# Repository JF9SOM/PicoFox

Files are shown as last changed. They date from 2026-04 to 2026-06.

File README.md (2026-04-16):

# PicoFox – A Hackable 2m Fox Transmitter

**PicoFox** is an open source fox transmitter for the 2-meter amateur band, built around the
RP2040 microcontroller (the same chip used in the Raspberry Pi Pico). It’s designed to be simple,
functional, and easy to modify.

PicoFox works well as a standalone fox for portable or walking hunts, but it’s also a great platform
for experimentation. There's ample CPU, flash, and GPIO available if you want to add features like
sensors or interactivity. The transmitter can generate a frequency or phase modulated signal with up
to 2.5kHz (data) bandwidth.

## Key Features
- Transmits FM in the 144–148 MHz band (ITU Zone 1: 144–146 MHz).
- Configured by editing a text file — no software or terminal needed.
- Transmits any 5kHz 16-bit PCM WAV file.
- Automatic Morse code ID with configurable tone, speed, and spacing.
- RF output > 18dBm at full power. Down to ~ -20dBm with full attenuation.
- Charges over USB.
- Expansion header provides:
  - 12 GPIOs (including I2C, SPI, UART, ADC).
  - Regulated 3.3V and raw battery voltage.
  - Two additional SI5351 clock outputs

### Getting One

Fully assembled PicoFox units are available from [AI6YM.radio](https://ai6ym.radio/picofox). An
enclosure, battery, and antenna are included. I ship nearly anywhere in the world.

You can also build your own - both the hardware and software are open source for non-commercial use.
For commercial inquiries, contact [justin@ai6ym.radio](mailto:justin@ai6ym.radio).

## Configuration

To configure your PicoFox, connect it to any computer using a micro USB cable. It will appear as a
USB mass storage device (like a flash drive). Open `settings.txt` with a text editor and adjust the
configuration values as needed. Eject the drive, disconnect USB, and power cycle the PicoFox to
apply the new settings.

To reset to factory settings, delete `settings.txt`, eject the drive, disconnect USB, and power
cycle the PicoFox. A default settings file will be regenerated.

### Settings Overview

- `CALLSIGN`: Alphanumeric callsign (max 12 characters).
- `ITU_ZONE`: ITU zone where the transmitter operates (`1`, `2`, or `3`).
- `FREQ_MHZ`: Transmit frequency in MHz.
- `ATTENUATION`: Attenuation level `0` - `127`, approximately 0.25dB steps.
- `DUTY_CYCLE`: Transmit duty cycle percentage (`0–100`).
- `MORSE_WPM`: Morse ID speed in words per minute.
- `MORSE_FARNSWORTH_WPM`: Slower Farnsworth spacing speed (ignored if lower than `MORSE_WPM`).
- `MORSE_TONE`: Morse tone frequency (100–2000 Hz).
- `MORSE_TONE_VOL`: Morse tone volume percentage (`1–100`).

**Note:** Invalid or missing values may disable the transmitter or revert to safe defaults.

## Using the Transmitter

After configuring settings as described above. The transmitter will turn on following the
provided settings the next time it is turned on.

The transmitter may be powered by an external USB power supply or the internal battery. The internal
battery charges over USB but no indication is available to show battery charging.

**Note: The power switch must be ON to charge the battery over USB. The transmitter will run on USB
power with the switch OFF but the battery will NOT be charged.**

A full battery will last about five hours at 100% duty cycle, 

## Replacing the Audio File

To change the audio transmission, replace the `audio.wav` file in the device’s flash storage. The
audio must be sampled at **5kHz**, **mono** (one channel), and encoded as **signed 16-bit PCM WAV**.

Using **Audacity** (free software available for all major OSs):

1. Set "Project Rate (Hz)" to `5000`.
2. Import, record, or generate your audio.
3. Mix down to a single mono track.
4. Export as WAV using **Signed 16-bit PCM** encoding.
5. Name the file `audio.wav` and copy it to the device.
6. Eject the drive and disconnect USB.
7. Power cycle the PicoFox.

**Notes:**

- Improper format may prevent audio transmission or cause noise to be transmitted instead.
- The audio is transmitted, followed by the morse ID, and then the transmitter turns off if
  `DUTY_CYCLE < 100`. In this way the length of the audio determines the transmit cycle time and the
  frequency of morse code ID transmissions. **YOU ARE RESPONSIBLE FOR COMPLYING WITH LOCAL LAWS FOR
  TRANSMITTING YOUR CALLSIGN!**
- To restore the default audio, delete `audio.wav`, eject the drive, disconnect USB, and power cycle
  the PicoFox.

## Design Brief

An SI5351 clock generator, locked to a TCXO, provides the RF signal. Modulation is applied in
software by the RP2040. To achieve smooth FM output, modulation is handled on core 1 with
I<sup>2</sup>C running at 1 MHz. Register writes are minimized and no other devices are on
I<sup>2</sup>C0.

Core 0 manages flash operations. Most extensions or new features should run on core 0.

**Note:** Mounting the device as a USB mass storage device will interrupt clean modulation as both
cores are blocked during flash operations.

The SPI flash device is split into program memory and a FAT16 filesystem. The filesystem contains
a text file for user-supplied settings, an audio file for transmission, a second audio file
containing the generated morse code ID, and a hash file used to detect changes to the settings file.
Unexpected files are automatically deleted and missing files are re-created from defaults in the
firmware binary.

The design intentionally includes large amounts of free CPU cycles, RAM, and flash so that cool
things can be built on the PicoFox.

## Development Guide

### Build Environment Setup

- Install Arduino IDE >= 2.3.
- Install libraries - Adafruit SPIFlash, Adafruit TinyUSB, Etherkit Si5351.
- Install board package from [my fork of Arduino-Pico](https://github.com/ai6ym/arduino-pico). This
  will be merged upstream eventually but for now you'll need the changes in my fork.
- In `Tools -> Board` select the `Raspberry Pi RP2040/RP2350 Boards -> AI6YM PicoFox`.
- Connect your PicoFox and select the appropriate TTY / COM port.

On Linux it may be necessary to add udev rules for this device. The relevant rules from my system
are below. I have no idea how this works on other operating systems. Mac is probably similar,
Windows should not be used for software developement of any kind (or really anything).

```
# Make an RP2040 in BOOTSEL mode writable by all users, so you can `picotool`
# without `sudo`. 
SUBSYSTEM=="usb", ATTRS{idVendor}=="2e8a", ATTRS{idProduct}=="0003", MODE="0666"

# Symlink an RP2040 running MicroPython from /dev/pico.
#
# Then you can `mpr connect $(realpath /dev/pico)`.
SUBSYSTEM=="tty", ATTRS{idVendor}=="2e8a", ATTRS{idProduct}=="0005", SYMLINK+="pico"

# Adafruit TinyUSB stack.
SUBSYSTEM=="tty", ATTRS{idVendor}=="239a", ATTRS{idProduct}=="cafe", MODE="0666"
SUBSYSTEM=="usb", ATTRS{idVendor}=="239a", ATTRS{idProduct}=="cafe", MODE="0666"
```

### Compilation Settings

- `Flash Size`: `16MB (Sketch: 1MB, FS: 15MB)`
- `CPU Speed`: `TBD`
- `USB Stack`: `Adafruit TinyUSB`

If needed for some reason you could change the partition layout to give more space for the sketch.
Doing so would destroy all data but the code automatically formats the partition and writes
defaults.

All other settings are fine at default values.

### Recovering a Board

In general the UF2 upload process will work fine. Click the upload button, after compilation the IDE
will push the board into UF2 update mode, write the new binary, and then reset the board to normal
operation.

If that doesn't work try the following:
- Reset the board and try again. Just tap the `RESET` button on the board to reset the RP2040.
- Force the device into `BOOTSEL` mode. Hold the `BOOTSEL` button, tap the `RESET` button, and then
  release the `BOOTSEL` button.
- Force the device into `BOOTSEL` mode **AND** change `Tools -> Upload Method` to `PicoTool`.
- When all else fails grab a PicoProbe (or a Pico / Pico2 flashed with the PicoProbe binary),
  connect that to the debug header of the PicoFox, and change `Tools -> Upload Method` to
  `Picoprobe`.
- If all of the above fails, well, he's dead Jim.

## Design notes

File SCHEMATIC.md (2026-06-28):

# 回路図 / Schematic Reference

テキストベースの回路図。ブレッドボード配線・実装の参考用。  
詳細なピン対応表は [`HARDWARE.md`](HARDWARE.md)、部品の入手先は [`BOM.md`](BOM.md) を参照。

---

## 1. システム全体ブロック図

```
                        ┌─────────────────────────────────────────────────────┐
                        │                  PicoFox 基板                        │
                        │                                                      │
   USB-C ───────────────┤ USBLC6  BQ21040 ←── USB 5V                          │
   (充電/MSC)           │  (ESD)  (充電IC)                                     │
                        │             │                                        │
   LiPo ────────────────┤        +BATT (3.7V)                                  │
   3.7V                 │             │                                        │
                        │         AO3401A ─── SW (電源スイッチ)                │
                        │         AO3407A                                      │
                        │             │                                        │
                        │        ME6217C33 ──→ +3V3 (内部, 最大500mA)          │
                        │                                                      │
                        │   ┌──────────────────┐                               │
                        │   │     RP2040        │                               │
                        │   │  W25Q128 (Flash)  │                               │
                        │   │  ABM8-272 (12MHz) │                               │
                        │   └────────┬──────────┘                               │
                        │            │ 拡張ヘッダ J1                            │
                        └────────────┼────────────────────────────────────────┘
                                     │
              ┌──────────────────────┼──────────────────────┐
              │                      │                      │
    ┌─────────▼──────────┐  ┌────────▼───────┐   ┌─────────▼──────┐
    │     DRA818V        │  │ 144MHz BPF     │   │  スタートボックス│
    │  (134〜174MHz FM)  │  │ (HobbyPCB /    │   │  (SYNC回路)    │
    │  内蔵PA ≈1W        │  │  LC自作)       │   └────────────────┘
    │  UART制御          │  └────────┬───────┘
    └─────────┬──────────┘           │
              │ RF Out               │ RF
              └──────────────────────┘
                                     │
                              ┌──────▼──────┐
                              │  SMAコネクタ │
                              │  50Ω アンテナ│
                              └─────────────┘
```

---

## 2. RP2040 ↔ DRA818V 接続図

```
   RP2040 (PicoFox 拡張ヘッダ J1)          DRA818V
   ┌──────────────────────────┐            ┌───────────────────────────┐
   │                          │            │                           │
   │  GPIO 8  (UART1 TX) ─────┼────────────┼──→ RXD   (コマンド受信)  │
   │                          │            │                           │
   │  GPIO 9  (UART1 RX) ←───┼────────────┼─── TXD   (応答送信)      │
   │                          │            │                           │
   │  GPIO10  (PTT)      ─────┼────────────┼──→ PTT   LOW=TX, HIGH=RX │
   │                          │            │                           │
   │  GPIO11  (PDN)      ─────┼────────────┼──→ PDN   HIGH=ON, LOW=PD │
   │                          │            │                           │
   │  GPIO12  (SQ_IN)    ←───┼────────────┼─── SQ    スケルチ出力     │
   │                     (未使用)          │         (Fox送信機では不使用)│
   │                          │            │                           │
   │  GPIO15  (PWM Audio)─────┼──[LPF]─────┼──→ MIC   音声入力        │
   │                          │            │                           │
   │  +3V3 ──────────────[外部3.3V/1A]─────┼──→ VCC   3.3V / 最大700mA│
   │                          │            │                           │
   │  GND  ──────────────────┼────────────┼─── GND                   │
   │                          │            │                           │
   │  GPIO13  (SYNC)     ←───┼─────────── ┼─ (スタートボックスへ)      │
   └──────────────────────────┘            └───────────────────────────┘

信号レベルはすべて 3.3V CMOS。レベル変換不要。
全信号線の長さは 10cm 以内を推奨。
```

---

## 3. PWM音声出力 LPF 回路図

RP2040のGPIO15から出力される10bit PWM（約122kHz）をアナログ音声に変換し、DRA818VのMICピンへ供給する。

```
                    R1            DRA818V
  GPIO15 ──────────[1kΩ]──────┬──→ MIC pin
  (PWM ~122kHz,               │
   10bit, 3.3Vp-p)          [C1]
                             [33nF]
                               │
                              GND (DRA818V GND と同一点)

  周波数特性:
  ────────────────────────────────────────────────
   周波数      ゲイン    用途
  ────────────────────────────────────────────────
   1 kHz       0 dB     モールストーン（通過）
   4.8 kHz    -3 dB     カットオフ周波数 fc
   10 kHz    -13 dB     減衰（PWM成分を抑制）
   122 kHz   -48 dB     PWMキャリア（十分減衰）
  ────────────────────────────────────────────────

  fc = 1 / (2π × 1kΩ × 33nF) ≈ 4.8 kHz

  代替値: R=1kΩ, C=47nF → fc ≈ 3.4 kHz（偏移を絞りたい場合）

  注意: C1 は DRA818V MICピンのすぐ近く（1cm以内）に配置すること。
```

---

## 4. SYNC・スタートボックス回路図

### 4-a. フォックス側 SYNC 入力回路（1台分）

```
  3.5mm ステレオジャック
  ┌─────────────┐
  │ Tip ────────┼──[R: 100Ω]───── GPIO13 (SYNC_PIN)
  │             │                    │
  │             │               [内部プルアップ 50kΩ]
  │             │                    │
  │ Ring ───────┼──────────────── +3V3
  │             │
  │ Sleeve ─────┼──────────────── GND
  └─────────────┘

  平常時: GPIO13 = HIGH（内部プルアップ）
  同期時: スタートボックスがTipをGNDに落とす → GPIO13 = LOW → エポックリセット
```

### 4-b. スタートボックス回路

```
                         3.5mm ジャック OUT
                         ┌─────────────┐
  +3V3 ──[10kΩ]──┬───── │ Tip         ├── ケーブルへ
                 │       │             │
                [SW1] ── │             │
  (タクトスイッチ)│       │ Ring ───────┼── GND
                GND      │ Sleeve ─────┼── GND
                         └─────────────┘

  SW1 OFF (平常): Tip = HIGH（プルアップ）
  SW1 ON  (押下): Tip = GND  → 全Foxの GPIO13 が LOW → 同期

  注: フォックス側の内部プルアップ（50kΩ）が5台並列になるため
      合成抵抗 ≈ 10kΩ。スタートボックスの外部プルアップは省略可。
```

### 4-c. 5台同時接続図（デイジーチェーン）

```
  スタートボックス
  ┌─────────────────┐
  │                 │
  │  SW1 ─── GND   │
  │   │             │
  │  [100Ω]        │
  │   │             │
  │  Tip────────────┼─── ケーブル1 ──┬── Fox1: Tip→[100Ω]→GPIO13
  │  Ring───── GND ─┼─── ケーブル1 ──┘   Fox1: Ring→GND
  │                 │
  └────────┬────────┘
           │ OUT ジャック
           │
           ├── ケーブル2 ──┬── Fox2: Tip→[100Ω]→GPIO13
           │              └── Fox2: Ring→GND
           │
           ├── ケーブル3 ──┬── Fox3: Tip→[100Ω]→GPIO13
           │              └── Fox3: Ring→GND
           │
           ├── ケーブル4 ──┬── Fox4: Tip→[100Ω]→GPIO13
           │              └── Fox4: Ring→GND
           │
           └── ケーブル5 ──┬── Fox5: Tip→[100Ω]→GPIO13
                          └── Fox5: Ring→GND

  TipラインはスタートボックスとFox5本が並列接続。
  SW1 を押すと全 Fox の GPIO13 が同時に LOW になる。
```

---

## 5. 電源回路図

```
  USB-C コネクタ
       │
  USBLC6-2SC6 (ESD保護)
       │
   VBUS (+5V) ──────────────────────────── RP2040 (USB電源時)
       │
  BQ21040DBVR (LiPoチャージャ)
       │ 充電電流
       ▼
  LiPo 3.7V ◄──── JST PH コネクタ ◄──── LiPo バッテリー (2000〜3000mAh)
       │
  AO3407A / AO3401A (電源スイッチ MOSFET)
       │
   SW (スライドスイッチ)
       │
  +BATT (3.7〜4.2V) ─────────────────────────────────────────────┐
       │                                                          │
  ME6217C33M5G (3.3V LDO, 最大500mA)                             │
       │                                                          │
   +3V3_INT ──→ RP2040, Si5351, W25Q128, USBLC6                  │
   (内部 3.3V)   各種プルアップ、ロジック回路                     │
                                                                  │
                                                         ┌────────▼────────┐
                                                         │  外部 3.3V 電源  │
                                                         │  (1A以上、別途)  │
                                                         │ ※DRA818V専用    │
                                                         └────────┬────────┘
                                                                  │
                                                            +3V3_DRA (3.3V / 1A)
                                                                  │
                                                             DRA818V VCC
                                                         (送信時 最大 700mA)

  デカップリング:
    +3V3_INT  各ICのVCC直近に 100nF + 1uF を配置
    +3V3_DRA  DRA818V VCCに 100uF(電解) + 100nF(セラミック) を並列配置
    +BATT     バッテリ端子近傍に 100uF を配置

  グランド接続:
    RP2040 GND ─┐
    DRA818V GND─┼── 1点でのみ接続（グランドループを防ぐ）
    BPF GND  ───┘
```

---

## 6. RF信号経路・アンテナ接続

```
  DRA818V
  ┌─────────────────────────┐
  │                         │
  │  内蔵 VCO + PLL          │
  │  134〜174 MHz            │
  │  内蔵 PA (≈1W / 30dBm)  │
  │                         │
  │  ANT ───────────────────┼── SMAケーブル (10cm, 50Ω) ──→ BPF IN
  │                         │
  └─────────────────────────┘

  144MHz BPF (HobbyPCB または LC自作)
  ┌──────────────────────────────┐
  │                              │
  IN ──┤ 通過帯域: 144〜146MHz    ├── OUT
  │    │ 挿入損失: ≈ 1〜2dB      │
  │    │ スプリアス抑制: > 40dBc  │
  │                              │
  └──────────────────────────────┘
       │
       └── SMAケーブル (10cm, 50Ω) ──→ SMAコネクタ (エッジマウント)
                                                │
                                          1/4λ アンテナ
                                          145MHz: 51.5cm
                                          (またはホイップ、Jポール等)

  インピーダンス: 全経路 50Ω
  BPFとSMAコネクタ間の配線は 5cm 以内を推奨。
  同軸ケーブルのシールドはグランドプレーンに確実に接続すること。

  アンテナ長の目安 (145.660 MHz):
  ────────────────────────────────
  1/4λ      = 300,000 / 145.660 / 4 ≈ 51.5 cm
  1/2λ DP   = 各エレメント ≈ 51.5 cm × 2
  5/8λ GP   ≈ 64.4 cm (利得 +3dBi)
  ────────────────────────────────
```

---

## 7. 完成系の信号フロー（まとめ）

```
  [LiPo] → [電源SW] → [LDO 3.3V] → [RP2040]
                                        │
                    ┌───────────────────┤
                    │                   │
              [UART 9600bps]      [PWM GPIO15]
                    │                   │
                    ▼                 [LPF]
              [DRA818V]                 │
              周波数設定 ←──────────── MIC
              PTT制御   ←── GPIO10
              PDN制御   ←── GPIO11
                    │
                   RF出力 (145.660 MHz, ≈1W)
                    │
                [144MHz BPF]
                    │
               [SMAコネクタ]
                    │
                [アンテナ]
                    ↑
              電波輻射 145.660/145.780 MHz FM

  [SYNC入力 GPIO13] ←── [スタートボックス SW1] ←── 運営者
       │
  エポックリセット → 60秒サイクル再開始 → 全Fox同期
```

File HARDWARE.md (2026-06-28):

# ハードウェア接続図 / Hardware Connection Guide

DRA818V換装構成の配線リファレンス。  
**注意**: DRA818V統合はStep 4以降の作業。現行ファームウェアはSi5351構成で動作する。

---

## 1. RP2040 ↔ DRA818V ピン接続表

| RP2040 GPIO | 信号名 | DRA818V ピン | 説明 |
|:---:|---|:---:|---|
| GPIO 8 | UART TX | RXD | コマンド送信（9600bps） |
| GPIO 9 | UART RX | TXD | 応答受信 |
| GPIO 10 | PTT | PTT | LOW=送信, HIGH=受信 |
| GPIO 11 | PDN | PDN | HIGH=通常動作, LOW=パワーダウン |
| GPIO 12 | SQ_IN | SQ | スケルチ出力（fox送信機では未使用） |
| GPIO 15 | PWM Audio | MIC | 音声入力（LPF経由）|
| 3V3 | VCC | VCC | 3.3V電源 |
| GND | GND | GND | グランド |

### 電源について

DRA818Vは3.3Vで動作するが**送信時に最大700mA**を消費する。  
PicoFox内蔵のME6217C33M5G LDO（最大500mA）では不足するため、**外部3.3V電源または5V→3.3V降圧モジュール（1A以上）**を別途用意すること。

---

## 2. RP2040 ↔ Si5351 ピン接続表（現行PicoFox基板）

| RP2040 GPIO | 信号名 | Si5351 ピン | 説明 |
|:---:|---|:---:|---|
| GPIO 0 | I2C0 SDA | SDA | I2Cデータ（1MHz） |
| GPIO 1 | I2C0 SCL | SCL | I2Cクロック（1MHz） |
| GPIO 2 | AMP_EN | — | アンプ制御（LOW=有効） |
| GPIO 4 | ATTN_LE | — | BVA1761アッテネータLatch Enable（r3のみ） |
| 3V3 | VCC | VDD | 3.3V電源 |
| GND | GND | GND | グランド |

Si5351のCLK0出力がRFアンプ（H5VU06B）に接続される。  
CLK1・CLK2は拡張ヘッダ経由で利用可能（将来の3.5MHz対応に使用予定）。

---

## 3. PWM LPF 回路定数

DRA818V MICピンへの音声入力用ローパスフィルタ。

```
GPIO 15 (PWM) ──[R1: 1kΩ]──┬── DRA818V MIC
                            │
                          [C1: 33nF]
                            │
                           GND
```

| 定数 | 値 | 計算根拠 |
|---|-----|---|
| R1 | 1 kΩ | インピーダンス整合 |
| C1 | 33 nF | fc = 1/(2π×1kΩ×33nF) ≈ **4.8 kHz** |
| PWM周波数 | 約122 kHz | 125MHz ÷ 1024 (10bit) |
| 通過帯域 | 〜4.8 kHz | 5kHzサンプルレート音声を通過 |

**代替値（よりシャープなカットオフ）**: R=1kΩ, C=47nF → fc ≈ 3.4 kHz  
DRA818Vの最大周波数偏移はデフォルト設定で±5kHz（25kHz帯域幅）または±2.5kHz（12.5kHz帯域幅）。

---

## 4. BVA1761 アッテネータ（r3基板のみ）

PicoFox r3にはSi5351出力後段にBVA1761デジタルアッテネータが搭載されている。

| RP2040 GPIO | 信号 | 説明 |
|:---:|---|---|
| GPIO 0 | DATA（SDA兼用） | シリアルデータ（LSBファースト） |
| GPIO 1 | CLK（SCL兼用） | シリアルクロック |
| GPIO 4 | LE | ラッチイネーブル（パルスで設定確定） |

Si5351初期化前にビットバング方式で設定する（ファームウェア実装済み）。  
DRA818V換装後はこのアッテネータは使用しない（DRA818V側でRFレベルを制御）。

---

## 5. ブレッドボード配線の注意事項

### RF系
- SMAコネクタからBPF、BPFからDRA818Vアンテナピンまでの配線は**できるだけ短く**（5cm以内）
- RFラインはグランドプレーンに近接させてインピーダンス50Ωを維持
- DRA818VのRFピンは直接触らない（静電気に弱い）

### 電源系
- DRA818V電源ラインには**100μF電解コンデンサ + 100nFセラミックコンデンサ**を並列に配置
- PTT切り替え時の電源ノイズが RP2040 にカップリングしないよう電源を分離する
- RP2040とDRA818Vのグランドは**1点でのみ接続**（グランドループを防ぐ）

### UART
- GPIO 8/9はPicoFox拡張ヘッダ（J1）経由で引き出す
- DRA818V TXD/RXDは3.3Vロジックなのでレベル変換不要

### PWM Audio
- LPFのC1（33nF）はDRA818V MICピンのすぐ近くに配置
- LPFのグランドはDRA818V GNDに直結（RP2040 GNDと同一点でのみ接続）

---

## 6. SYNC配線（スタートボックス接続）

### SYNC_PINのピン番号

| RP2040 GPIO | 信号 | 方向 | 説明 |
|:---:|---|:----:|---|
| GPIO 13 | SYNC | 入力 | アクティブLOWパルスで60秒サイクルをリセット。内部プルアップ有効。 |

### 同期ケーブル配線図

スタートボックスから各フォックスに3.5mmステレオケーブルを数珠繋ぎにする。

```
スタートボックス
┌────────────────────────────┐
│  [SW1]                     │
│   ├── 100Ω ── SYNC(Tip)   ●── 3.5mm ジャック OUT
│  GND ────────── GND(Ring) ●
└────────────────────────────┘
         │
         ├── ケーブル → Fox 1 (GPIO 13 / GND)
         ├── ケーブル → Fox 2 (GPIO 13 / GND)
         ├── ケーブル → Fox 3 (GPIO 13 / GND)
         ├── ケーブル → Fox 4 (GPIO 13 / GND)
         └── ケーブル → Fox 5 (GPIO 13 / GND)
```

各フォックス側のジャック配線:

```
3.5mm ステレオジャック（各Fox搭載）
  Tip   ── 100Ω ── GPIO 13 (SYNC_PIN, INPUT_PULLUP)
  Ring  ──────────── GND
  Sleeve ─────────── GND（シールド）
```

**直列100Ω抵抗**はESD保護と静電気対策。省略可能だが推奨。

### スタートボックス回路

```
      VCC (3.3V または 5V)
         │
        [10kΩ] ← プルアップ（フォックス側の内部プルアップで代替可）
         │
SYNC ───┤├── SW1 (タクトスイッチ) ── GND
         │
        [100Ω] ── 3.5mm Tip（OUT）
         │
       3.5mm Ring/Sleeve ── GND
```

**操作手順**:
1. 全フォックスをSYNCケーブルで接続し電源を投入
2. スタートボックスのSW1を押す（SYNC線がLOWになり全フォックスのエポックがリセット）
3. SW1を離す（全フォックスが同時に60秒サイクルを再開始）

**注意**:
- SYNCケーブルはイベント開始直前に接続し、完了後は外す（誤同期防止）
- ケーブルの接触不良でSYNCが入らない場合、各局は電源投入時刻を基準に動作する

---

## 7. 接続確認チェックリスト（組み立て後）

- [ ] DRA818V VCC = 3.3V（テスター確認）
- [ ] DRA818V PDN = HIGH（テスター確認）
- [ ] Serial1でAT+DMOCONNECTに"+DMOCONNECT:0"が返る
- [ ] PTT LOWでRP2040の電源電圧が3.1V以上を維持（電流確認）
- [ ] RTL-SDRで145.660 MHzにキャリアが見える
- [ ] モールスIDが受信できる

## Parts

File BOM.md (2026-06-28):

# 部品表 (BOM) / Bill of Materials

日本ARDF競技向けPicoFox（DRA818V構成）の統合部品表。  
**前提**: RF送信モジュールはDRA818Vを使用する。Si5351A関連部品はオリジナルPicoFox基板に搭載済みのため、新規調達は不要（注記参照）。

価格は2024年時点の参考値。為替・在庫状況により変動する。  
数量は特記のない限り **フォックス1台分**。

---

## 1. メインコントローラ

| 部品名 | 型番 | 数量 | 用途 | 入手先 | 参考価格（円） |
|---|---|:----:|---|---|:---:|
| MCU | RP2040 | 1 | メインマイコン（QFN-56） | Mouser Japan / DigiKey Japan | 150 |
| SPI Flash | W25Q128JVS | 1 | 16MB ファームウェア・ファイルシステム | DigiKey Japan / AliExpress | 120 |
| クリスタル | ABM8-272 12MHz | 1 | RP2040 USB PLL用 | DigiKey Japan | 200 |

**小計: 約470円**

---

## 2. RF送信モジュール

| 部品名 | 型番 | 数量 | 用途 | 入手先 | 参考価格（円） |
|---|---|:----:|---|---|:---:|
| VHF FM送受信モジュール | **DRA818V** | 1 | 134〜174MHz FM変調、内蔵PA（出力約1W） | AliExpress / eBay | 700〜1,200 |
| SMAケーブル | SMA-SMA 10cm | 1 | DRA818V〜BPF間RF接続 | 秋月電子 / AliExpress | 200〜400 |
| ピンヘッダ | 2.54mm オス 1×6 | 1 | 拡張ヘッダ経由DRA818V接続用 | 秋月電子 | 50 |

> **オリジナル構成（DRA818V使用時は不要）**: Si5351A-B-GT、TCXO（TG2016SMN 25MHz）、BVA1761デジタルアッテネータ、RF MMIC（H5VU06B）はオリジナルPicoFox基板に搭載済み。DRA818V換装後はこれらを使用しない。

**小計: 約950〜1,650円**

---

## 3. フィルタ

| 部品名 | 型番・仕様 | 数量 | 用途 | 入手先 | 参考価格（円） |
|---|---|:----:|---|---|:---:|
| 144MHz BPF | HobbyPCB 144MHz BPF | 1 | スプリアス抑制用バンドパスフィルタ | hobbypcb.com（海外通販） | 1,500〜2,000 |
| 144MHz BPF（代替） | 自作 LC回路（コイル+コンデンサ） | 1 | 上記が入手困難な場合の代替 | 秋月電子 | 200〜500 |
| PWM LPF | R=1kΩ + C=33nF | 1組 | PWM音声→DRA818V MICピン平滑化 | 秋月電子 | 50 |

> BPFはHobbyPCBまたは自作のいずれか1つを選択。両方は不要。

**小計: 約250〜2,050円**（BPF選択による）

---

## 4. 電源

| 部品名 | 型番 | 数量 | 用途 | 入手先 | 参考価格（円） |
|---|---|:----:|---|---|:---:|
| LiPoチャージャ | BQ21040DBVR | 1 | USB-Cでのバッテリー充電 | DigiKey Japan / Mouser Japan | 200 |
| LDOレギュレータ | ME6217C33M5G | 1 | 3.3V生成（SOT-23-5） | AliExpress / DigiKey Japan | 80 |
| USB ESD保護 | USBLC6-2SC6 | 1 | USB端子のESD保護 | Mouser Japan / DigiKey Japan | 100 |
| MOSFETスイッチ | AO3401A | 1 | 電源スイッチング（P-ch SOT-23） | 秋月電子 / AliExpress | 30 |
| MOSFETスイッチ | AO3407A | 1 | 電源スイッチング（P-ch SOT-23） | 秋月電子 / AliExpress | 30 |
| LiPoバッテリー | 3.7V 2000〜3000mAh JST PH | 1 | 主電源（約5時間@フル送信） | 秋月電子 / AliExpress | 800〜1,500 |
| USB-Cレセプタクル | HC-TYPE-C-16P-01A | 1 | 充電・USB MSC接続 | AliExpress / 千石電商 | 80 |
| スライドスイッチ | SK12D07VG5 | 1 | 電源ON/OFF | 秋月電子 / 千石電商 | 30 |
| バッテリコネクタ | JST PH 2pin水平 | 1 | LiPoバッテリー接続 | 秋月電子 / 千石電商 | 50 |

> **DRA818V送信時の電流**: 最大700mA。内蔵LDOだけでは不足するため、**外部3.3V/1A以上の電源ラインをDRA818Vに直結**すること（[`HARDWARE.md`](HARDWARE.md) §1参照）。

**小計: 約1,400〜2,100円**

---

## 5. 同期・スタートボックス

フォックス全台の60秒サイクルを同時起動するためのSYNCシステム。  
スタートボックス部品（ケース等）は**5台分で1セット**。

### フォックス搭載部品（1台ごと）

| 部品名 | 型番・仕様 | 数量 | 用途 | 入手先 | 参考価格（円） |
|---|---|:----:|---|---|:---:|
| 3.5mmステレオジャック | MJ-354W / SJ-3523-SMT 等 | 1 | SYNCケーブル受け口（Tip=SYNC, Ring=GND） | 秋月電子 / 千石電商 | 60〜100 |
| 抵抗 | 100Ω 1/4W | 1 | SYNC線ESD保護 | 秋月電子 | 5 |

**フォックス搭載小計: 約65〜105円/台**

### スタートボックス（5台共用・1セット）

| 部品名 | 型番・仕様 | 数量 | 用途 | 入手先 | 参考価格（円） |
|---|---|:----:|---|---|:---:|
| 3.5mmステレオジャック（パネル用） | MJ-073N 等 | 2 | IN/OUTデイジーチェーン用 | 秋月電子 / 千石電商 | 80〜150 |
| 3.5mmステレオケーブル | 1〜2m オス-オス | 5本 | スタートボックス〜各フォックス間 | 100円ショップ / AliExpress | 500〜1,500 |
| タクトスイッチ | 6mm角、高さ5mm以上 | 1 | スタートボタン | 秋月電子 | 20 |
| 抵抗 | 100Ω 1/4W | 1 | SYNC線ESD保護 | 秋月電子 | 5 |
| プラスチックケース | タカチ SW-65B 等（65×50×20mm） | 1 | スタートボックス筐体 | 秋月電子 / 千石電商 | 300〜600 |

**スタートボックス小計: 約905〜2,275円（5台分）**

---

## 6. パッシブ部品・その他

| 部品名 | 仕様 | 数量 | 用途 | 入手先 | 参考価格（円） |
|---|---|:----:|---|---|:---:|
| コンデンサ | 100nF 0402 | 多数 | デカップリング | 秋月電子 / AliExpress | 200（アソート） |
| コンデンサ | 1uF / 10uF 0402 | 数個 | バイパス・電源平滑 | 秋月電子 | 150 |
| インダクタ | 68nH / 270nH 0402 | 各数個 | RF整合回路（Si5351構成用） | Mouser Japan / AliExpress | 300 |
| フェライトビーズ | 0402 | 数個 | 電源ノイズ除去 | 秋月電子 / AliExpress | 100 |
| 抵抗 | 各種 0402 | 多数 | プルアップ・分圧等 | 秋月電子 | 200（アソート） |
| ダイオード | 1N4148WS SOD-323 | 数個 | 逆流防止等 | 秋月電子 / 千石電商 | 50 |
| LED | 側面発光 1206 | 1 | ステータス表示 | 秋月電子 | 30 |
| SMAコネクタ | SMA エッジマウント | 1 | アンテナ接続 | 秋月電子 / Mouser Japan | 150 |
| タクトスイッチ | 6mm角 SMD | 1 | RESETボタン | 秋月電子 / 千石電商 | 20 |
| 拡張ヘッダ | 2×10 2.54mmピッチ | 1 | GPIO拡張 | 秋月電子 | 80 |

**小計: 約1,280円**

---

## 合計概算

### フォックス1台あたり

| カテゴリ | 下限（円） | 上限（円） |
|---|---:|---:|
| 1. メインコントローラ | 470 | 470 |
| 2. RF送信モジュール | 950 | 1,650 |
| 3. フィルタ（BPF含む） | 250 | 2,050 |
| 4. 電源（LiPo含む） | 1,400 | 2,100 |
| 5. 同期（フォックス分のみ） | 65 | 105 |
| 6. パッシブ部品・その他 | 1,280 | 1,280 |
| **合計（1台）** | **4,415** | **7,655** |

### スタートボックス（5台共用）

| | 下限（円） | 上限（円） |
|-|---:|---:|
| スタートボックス一式 | 905 | 2,275 |
| **1台あたり按分** | **181** | **455** |

### 5台フルセット合計目安

| | 下限（円） | 上限（円） |
|-|---:|---:|
| フォックス × 5台 | 22,075 | 38,275 |
| スタートボックス × 1セット | 905 | 2,275 |
| **総合計** | **約23,000** | **約40,500** |

> HobbyPCB BPFを使用した場合は上限寄り、LC自作BPFの場合は下限寄りになる。  
> オリジナルPicoFox基板（Si5351構成）を流用する場合、カテゴリ1・6の部品は調達不要のため1台あたり約1,750〜3,800円の削減になる。

---

## 入手先リンク（参考）

| ショップ | URL | 特徴 |
|---|-----|---|
| 秋月電子通商 | akizukidenshi.com | 国内最大手、即日発送 |
| 千石電商 | sengoku.co.jp | 秋葉原実店舗あり |
| Mouser Japan | mouser.jp | 正規代理店、幅広い品揃え |
| DigiKey Japan | digikey.jp | 正規代理店、在庫豊富 |
| AliExpress | aliexpress.com | 安価だが納期2〜4週間 |
| eBay | ebay.com | DRA818V等のモジュール類 |
| HobbyPCB | hobbypcb.com | ARDF・アマチュア無線向けBPF専門 |

---

## 注意事項

- 本機は自作のアマチュア無線機器です。日本国内で送信するには、アマチュア局免許状が必要ですが、自作機器の場合、JARDの保証認定を受けることでアマチュア局の開設または変更申請が可能です。
- HobbyPCB BPFはUSAからの取り寄せ。代替としてMini-Circuits等のSAWフィルタも検討可能。
- SMDパッシブ部品は秋月電子の「抵抗・コンデンサアソートセット」が割安。
- LiPoバッテリーは航空便不可のため、AliExpressからの発送に注意。

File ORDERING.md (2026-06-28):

# 発注ガイド / Ordering Guide

5台フルセット（フォックス5台＋スタートボックス1式）を前提とした発注手順。  
価格・在庫は変動するため、発注前に各ショップで最新情報を確認すること。

---

## 1. 発注先一覧

| ルート | ショップ | リードタイム | 特徴 |
|---|---|:---:|---|
| 🇺🇸 米国 | rfpowertools.com | 2〜3週間 | 144MHz BPF専門。品質安定、まとめ買い推奨 |
| 🇨🇳 中国 | AliExpress | 2〜4週間 | DRA818V・測定器。偽物に注意 |
| 🇯🇵 国内 | 秋月電子通商 | 翌日〜3日 | パッシブ部品・Pico・スイッチ類 |
| 🇯🇵 国内 | Amazon.co.jp | 翌日〜2日 | 急ぎの代替。割高な場合が多い |

---

## 2. 部品別発注先

### 🇺🇸 rfpowertools.com（米国）

**発注品目: 144MHz BPF × 5**

| 品目 | 数量 | 単価目安 | 合計目安 |
|---|:----:|---:|---:|
| 144MHz Band Pass Filter | 5 | $12〜$18 | $60〜$90 |
| 国際送料（USPS First Class / Priority） | — | $15〜$25 | — |
| **合計（5台分・送料込み）** | | | **$75〜$115（約11,000〜17,000円）** |

**まとめ買い推奨の理由**:
- 国際送料はほぼ固定のため、1個ずつ発注すると1個あたりの送料負担が大きい
- 5個発注で送料を5台に分散でき、1台あたりの追加コストを最小化できる
- BPFの予備（故障・紛失対策）として1〜2個多めに発注しておくと安心

**発注手順**:
1. rfpowertools.com にアクセスし "144MHz" または "2 meter BPF" で検索
2. 5個カートに追加
3. チェックアウト時に配送先を日本に設定、送料を確認
4. 支払いはクレジットカード（Visa/Mastercard）またはPayPal

> **備考**: BOM.mdでは hobbypcb.com も選択肢として記載している。rfpowertools.com で見つからない場合は hobbypcb.com の "144MHz BPF" も確認すること。

---

### 🇨🇳 AliExpress（中国直送）

#### DRA818V × 5

| 品目 | 数量 | 単価目安 | 合計目安 |
|---|:----:|---:|---:|
| DRA818V VHF Transceiver Module | 5 | ¥700〜¥1,200 | ¥3,500〜¥6,000 |
| 送料 | — | 無料〜¥300 | — |

**検索キーワード**: `DRA818V` / `DRA818 VHF module` / `SA818V`

**注意事項**:
- DRA818VはDRA818Uと**混同しやすい**。DRA818V = VHF（134〜174MHz）、DRA818U = UHF（400〜480MHz）。必ずVを確認すること
- SA818Vは後継・互換品として流通しているが、コマンド体系はほぼ同一
- 複数の出品者から1個ずつ試し買いして動作確認してから残数を発注するのが安全
- 評価件数1,000件以上・評価率95%以上のショップを選ぶ
- 到着後は即座にAT+DMOCONNECTで動作確認（[`TESTING.md §4`](TESTING.md) 参照）

#### tinySA Ultra × 1（スプリアス測定用）

| 品目 | 数量 | 単価目安 | 合計目安 |
|---|:----:|---:|---:|
| tinySA Ultra | 1 | ¥8,000〜¥12,000 | ¥8,000〜¥12,000 |
| 送料 | — | 無料〜¥500 | — |

**検索キーワード**: `tinySA Ultra` / `tiny SA ultra spectrum analyzer`

**⚠️ クローン品に注意**:
- tinySA Ultraには多数のクローン品・偽物が出回っている
- **公式販売店**: AliExpress内 "hugen79 official store" または "RF Technology store"
- 公式サイト: [tinySA.org](https://www.tinySA.org/) に正規販売店リストあり
- 価格が極端に安いもの（¥5,000以下）はクローン品の可能性が高い
- ファームウェアアップデートができないクローン品は測定精度が保証されない
- **購入前に tinySA.org の公式ショップリストで出品者を確認**すること

---

### 🇯🇵 秋月電子通商（国内）

**通販サイト**: akizukidenshi.com

#### Raspberry Pi Pico × 5（開発・テスト用）

> **注意**: PicoFox基板はRP2040チップを直接実装している。Picoモジュールは**PicoFox基板の代替にはならない**が、ファームウェア開発・動作確認・PicoProbeとしての利用に使える。

| 品目 | 数量 | 単価目安 | 合計目安 |
|---|:----:|---:|---:|
| Raspberry Pi Pico | 5 | ¥700〜¥800 | ¥3,500〜¥4,000 |

**活用方法**:
- ファームウェアの動作確認（RP2040互換）
- PicoProbeとしてPicoFox基板のデバッグに使用
- 1台をPicoProbeにするため2個あると便利

#### パッシブ部品・その他

| 品目 | 数量 | 単価目安 | 合計目安 |
|---|:----:|---:|---:|
| 抵抗アソートセット（1/4W） | 1 | ¥500〜¥800 | — |
| セラミックコンデンサアソート（0.1μF〜10μF） | 1 | ¥300〜¥500 | — |
| ジャンパワイヤセット | 1 | ¥300〜¥500 | — |
| SMAコネクタ（エッジマウント） | 5 | ¥150 | ¥750 |
| SMA-SMAケーブル 10cm | 5〜10 | ¥200〜¥400 | ¥1,000〜¥2,000 |
| 3.5mmステレオジャック（基板用） | 5 | ¥60〜¥100 | ¥300〜¥500 |
| 3.5mmステレオジャック（パネル用） | 2 | ¥80〜¥150 | ¥160〜¥300 |
| タクトスイッチ 6mm | 10 | ¥20 | ¥200 |
| スライドスイッチ | 5 | ¥30 | ¥150 |
| JST PHコネクタ 2pin | 5 | ¥50 | ¥250 |
| LiPoバッテリー 3.7V 2000mAh | 5 | ¥800〜¥1,200 | ¥4,000〜¥6,000 |
| タカチ SW-65B プラケース | 1 | ¥300〜¥600 | — |

**秋月電子での購入のコツ**:
- 通販注文は¥2,000以上で送料無料（2024年時点）
- 秋葉原実店舗では現物確認できる（日曜定休に注意）
- 部品の型番検索より「用途名」で検索した方が見つかりやすい場合あり

---

### 🇯🇵 Amazon.co.jp（予備・急ぎの場合）

以下は秋月電子に在庫がない場合や急ぎの場合の代替。基本的に秋月電子より割高。

| 品目 | 検索キーワード | 目安価格 |
|---|---|---:|
| Raspberry Pi Pico | "Raspberry Pi Pico SC0915" | ¥900〜¥1,200 |
| 3.5mmステレオケーブル 1m | "3.5mm ステレオ ミニプラグ" | ¥200〜¥500 |
| LiPoバッテリー | "リポバッテリー 3.7V 2000mAh JST PH" | ¥1,000〜¥2,000 |
| ブレッドボード | "ブレッドボード 400ポイント" | ¥300〜¥600 |

---

## 3. 発注の順序と優先度

リードタイムの長い海外便から先に発注する。

```
【第1週】海外発注（同時並行）
  ├─ rfpowertools.com: 144MHz BPF × 5（リードタイム 2〜3週間）
  └─ AliExpress:      DRA818V × 5    （リードタイム 2〜4週間）
                      tinySA Ultra × 1（リードタイム 2〜4週間）

【第1〜2週】国内発注（届き次第作業開始可能）
  └─ 秋月電子: Pico × 5、パッシブ部品、LiPo、ケーブル類
               → 翌日〜3日で到着

【第2週〜】到着次第作業開始
  ├─ 秋月電子部品到着 → ブレッドボードで配線確認・ファームウェア動作確認
  ├─ DRA818V到着     → TESTING.md §4 の初期確認手順を実施
  └─ BPF到着        → DRA818V + BPF でスプリアス測定（TESTING.md §3）

【第3〜4週】5局同時テスト
  └─ 全部品揃い次第 → TESTING.md §2 の5局同時起動テスト
```

**優先度まとめ**:

| 優先度 | 品目 | 理由 |
|:---:|---|---|
| ★★★ | DRA818V × 5 | 最重要部品、リードタイム長い |
| ★★★ | 144MHz BPF × 5 | 電波法上必須、リードタイム長い |
| ★★☆ | tinySA Ultra | スプリアス確認に必要 |
| ★★☆ | Pico × 5 | 開発・デバッグに即使える |
| ★☆☆ | パッシブ部品・ケーブル | 国内調達で即入手可能 |
| ★☆☆ | LiPoバッテリー | 国内調達、ただし航空便不可に注意 |

---

## 4. 注意事項

### LiPoバッテリーは航空便不可

- リチウムポリマーバッテリーは**国際航空便（SAL便含む）での輸送が禁止または制限**されている
- AliExpressで注文すると「船便のみ」となり**納期が6〜8週間**になる場合がある
- **国内（秋月電子・Amazonなど）での調達を強く推奨**

### tinySA Ultraのクローン品に注意

- AliExpressには公式品と外観が酷似したクローンが多数出回っている
- クローン品は測定精度・ファームウェアサポートが保証されない
- **必ず tinySA.org で公式販売店を確認してから発注する**
- 公式品には「tinySA.org」のロゴとシリアル番号が付属

### BPFは5台分まとめて発注

- rfpowertools.comへの国際送料は個数によらずほぼ固定
- 1台ずつ発注すると送料が5倍かかる
- 予備1〜2個を含め**6〜7個まとめて発注**するとコスト効率が良い

### 電波法：免許について

本機は自作のアマチュア無線機器です。日本国内で送信するには、アマチュア局免許状が必要ですが、自作機器の場合、JARDの保証認定を受けることでアマチュア局の開設または変更申請が可能です。

---

## 5. 発注チェックリスト

```
海外発注
[ ] rfpowertools.com: 144MHz BPF × 5（〜7）発注完了
[ ] AliExpress: DRA818V × 5 発注完了（公式ショップ確認済み）
[ ] AliExpress: tinySA Ultra × 1 発注完了（hugen79公式確認済み）

国内発注
[ ] 秋月電子: Raspberry Pi Pico × 5 発注完了
[ ] 秋月電子: LiPoバッテリー × 5 発注完了
[ ] 秋月電子: パッシブ部品・コネクタ・ケーブル類 発注完了
[ ] スタートボックス用ケース・スイッチ類 発注完了

到着確認
[ ] DRA818V AT+DMOCONNECT 動作確認（TESTING.md §4-Step1）
[ ] 144MHz BPF 通過損失確認（tinySA）
[ ] RTL-SDRでキャリア確認（免許取得後）
```

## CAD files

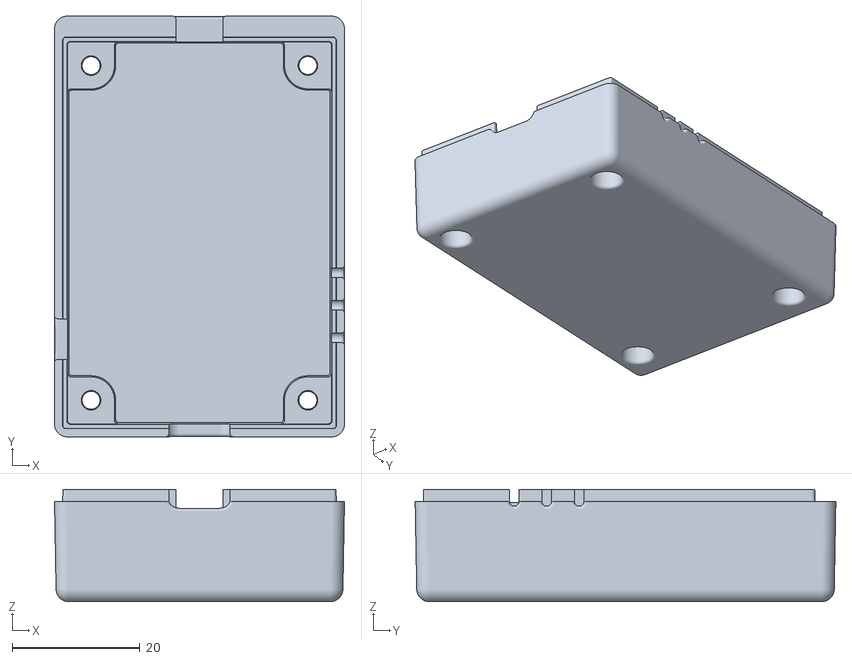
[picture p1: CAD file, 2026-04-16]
enclosure/Enclosure Bottom.stl
45.5 x 66.0 x 17.6

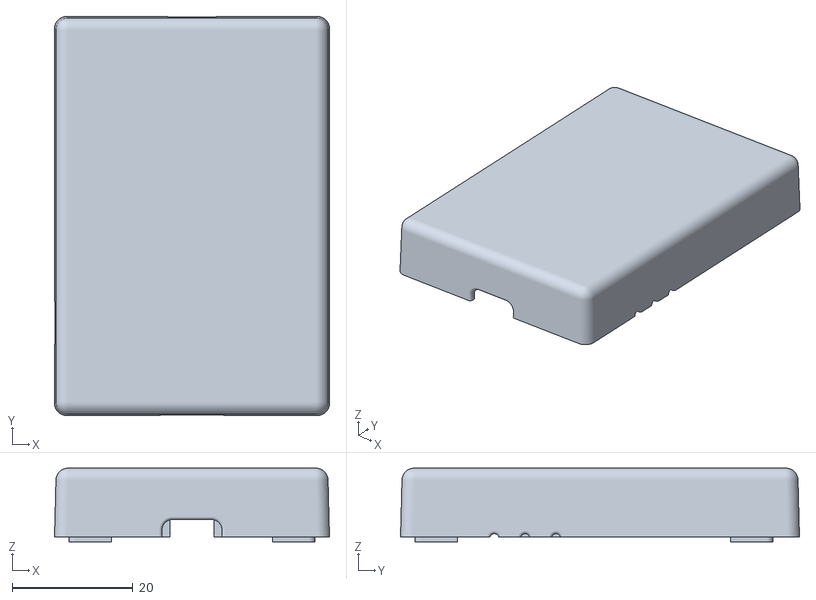
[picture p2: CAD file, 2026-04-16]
enclosure/Enclosure Top.stl
45.5 x 66.0 x 12.2

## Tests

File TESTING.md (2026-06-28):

# テスト手順書 / Testing Guide

---

## 1. RTL-SDRでの受信確認手順

### 必要機材
- RTL-SDR（RTL2832U系 USB SDRドングル）
- 145MHz帯対応アンテナ（1/4λ垂直 ≒ 51.5cm）
- PC: SDR# / GQRX / SDR++ いずれか

### 手順

**1-1. ソフトウェアセットアップ**
```
SDR# (Windows): sdrsharp.com からダウンロード
GQRX (Linux/Mac): sudo apt install gqrx-sdr
SDR++ (全OS): github.com/AlexandreRouma/SDRPlusPlus
```

**1-2. キャリア確認**
1. RTL-SDRを接続し、ソフトを起動
2. 周波数を `145.660 MHz` に設定
3. モード: `FM Narrow (NFM)`、帯域幅: `12.5 kHz`
4. PicoFoxに `CALLSIGN=JA1XXX`（任意）、`FOX_NUMBER=1` を設定して電源投入
5. 電源投入から **0秒以内** にキャリアが見えることを確認
6. 約10秒後にモールスID（MOE JA1XXX）が聞こえることを確認
7. 12秒でキャリアがOFFになることを確認

**1-3. スロットタイミング確認（単体）**
- SDR#のウォーターフォール表示で `FOX_NUMBER=1`〜`5` 各設定の送信開始時刻をストップウォッチで計測
- 期待値: Fox N の送信開始 = 電源投入から `(N-1) × 12秒`

---

## 2. 5局同時起動のスロット確認方法

### 事前準備
- PicoFox（またはシミュレーション用PC）を5台用意
- 各機に `FOX_NUMBER=1`〜`5` を設定（周波数はすべて同一: 145.660 MHz）

### シミュレーション方法（実機1台でテスト）
1台のPicoFoxで `FOX_NUMBER=1` から `5` に順次変更し、各スロット開始時刻を計測して確認する。

### 実機5台での確認手順

**2-1. 同時投入**
1. 5台を電源スイッチOFFの状態でUSB給電スタンバイ
2. 5台のスライドスイッチを**できるだけ同時**にON（±1秒以内が目標）
3. RTL-SDRのウォーターフォールを録画（OBS等）

**2-2. 確認ポイント**
```
秒数    期待動作
 0〜12  Fox1(MOE)のみ送信
12〜24  Fox2(MOI)のみ送信
24〜36  Fox3(MOS)のみ送信
36〜48  Fox4(MOH)のみ送信
48〜60  Fox5(MO5)のみ送信
60〜    Fox1(MOE)に戻る
```

**2-3. スロット重複の確認**
ウォーターフォール上で2局以上のキャリアが同時に見えた場合はスロット重複。  
原因: 電源投入タイミングのズレ（±1秒超）または `FOX_NUMBER` 設定ミス。

---

## 3. tinySAでのスプリアス測定手順

### 必要機材
- tinySA Ultra（推奨）またはtinySA Basic
- 50dBアッテネータ（直接接続時の保護用）
- SMA-SMAケーブル

### 手順

**3-1. 基本スプリアス測定**
1. PicoFoxのアンテナ端子に **50dBアッテネータ** を接続
2. アッテネータ出力をtinySAのIN端子に接続
3. tinySAの設定:
   - SPAN: `100 MHz〜500 MHz`（高調波確認）
   - RBW: `30 kHz`
4. PicoFoxを送信状態にして測定
5. 基本波（145.660 MHz）と第2高調波（291.32 MHz）、第3高調波（436.98 MHz）の電力差を確認

**3-2. 合否基準（電波法 第7条関係）**
- 基本波から **-60 dBc 以下**（スプリアス発射の強度の許容値）

**3-3. BPFありの比較測定**
HobbyPCB 144MHz BPFを挿入した状態で同様に測定し、スプリアス改善量を確認。

---

## 4. DRA818V到着後の初期確認手順

### Step 1: 単体動作確認（RP2040なし）

1. DRA818VのVCC=3.3V、GND接続
2. PDNをHIGHに固定
3. PCのUSB-シリアルアダプタ（3.3V）でRXD/TXDに接続
4. ターミナルソフト（Tera Term等）で `9600bps 8N1` に設定
5. 送信: `AT+DMOCONNECT\r\n`
6. 受信: `+DMOCONNECT:0` が返ればOK

**確認コマンド一覧**
```
AT+DMOCONNECT                          → ハンドシェイク確認
AT+DMOSETGROUP=1,145.6600,145.6600,0000,0,0000  → 145.660MHz / 12.5kHz設定
AT+DMOSETGROUP=0,145.6600,145.6600,0000,0,0000  → 145.660MHz / 25kHz設定
```

### Step 2: PTT動作確認

1. PTTピンをGNDに接続（LOW固定）
2. RTL-SDRで145.660 MHzにキャリアが見えるか確認
3. PTTをHIGHに戻してキャリアが消えるか確認

### Step 3: 音声変調確認

1. ファンクションジェネレータまたはスマートフォンの信号音（1kHzトーン）をMICピンに入力
2. PTT LOW（送信状態）
3. RTL-SDRのFMデモジュレータで1kHzトーンが聞こえるか確認
4. 音量を調整してFM偏移が ±2.5kHz（12.5kHz帯域幅モード）に収まるか確認

### Step 4: RP2040との統合確認

1. [`HARDWARE.md`](HARDWARE.md) の配線表に従って接続
2. `dra818_init()` を呼び出してシリアルモニタに初期化ログを確認
3. `dra818_set_group(145.660, DRA818_BW_12K5, 0)` を呼び出して周波数設定確認
4. `dra818_ptt_on()` でキャリア確認、`dra818_ptt_off()` でキャリア消滅確認
5. PWM音声出力からモールスIDが正常に変調されるか確認

---

## 5. 問題発生時のトラブルシューティング

| 症状 | 確認項目 |
|---|---|
| キャリアが出ない | isConfigured フラグ確認、CALLSIGN設定確認 |
| スロットがずれる | 全局同時投入できているか、millis()オーバーフロー確認 |
| DRA818Vが応答しない | UART TX/RXの逆接確認、PDN=HIGH確認、ボーレート確認 |
| モールスIDが聞こえない | callsign.wavが生成されているか、USBマウント中でないか |
| スプリアスが多い | BPFを挿入、Si5351駆動レベルを `SI5351_DRIVE_2MA` に維持 |
| 送信電力が低い | ATTENUATION=0 確認、DRA818V VCC電流確認（700mA必要） |

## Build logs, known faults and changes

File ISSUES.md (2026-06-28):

# 今後のタスク / Issue Tracker

GitHub Issuesの代替として、実装予定タスクをここで管理する。  
実際のIssueはリポジトリのIssuesタブへ移行予定。

---

## 進行中 / In Progress

なし

---

## 未着手 / Open

### Step 4: DRA818V UARTドライバ実装

**概要**: `dra818.h` / `dra818.cpp` のスタブを実機で検証し、`firmware.ino` に統合する。

**作業内容**:
- [ ] DRA818V実機でAT+DMOCONNECTの動作確認
- [ ] `dra818_init()` を `setup()` に組み込む
- [ ] `setSi5351Output()` の代替として `dra818_ptt_on/off()` を接続
- [ ] Si5351初期化ブロックをコンパイル時フラグ（`#ifdef USE_DRA818`）で分岐
- [ ] 設定変更時の再初期化対応（`FREQ_MHZ` 変更 → `dra818_set_group()` 再呼び出し）

**依存**: DRA818Vモジュール到着後に着手

---

### Step 5: PWM音声出力実装

**概要**: `pwm_audio.h` のスタブを実装し、`playAudio()` 内の `setFrequencyOffset()` を `pwm_audio_write()` に置き換える。

**作業内容**:
- [ ] `pwm_audio_init()` の実装（`pwm_gpio_to_slice_num` / `pwm_set_wrap` 設定）
- [ ] `pwm_audio_write(int16_t sample)` の実装
- [ ] `playAudio()` 内の `setFrequencyOffset(deviation)` を `pwm_audio_write(sample)` に置き換え
- [ ] LPF定数の実測（オシロスコープまたはSDRで波形確認）
- [ ] `AUDIO_PWM_SCALE` 定数の調整（FM偏移が ±2.5kHz に収まるよう調整）

**依存**: Step 4完了後、DRA818V実機でのテスト必要

---

### Step 6: 実機統合テスト

**概要**: Si5351構成とDRA818V構成を切り替えてARDF競技として動作することを確認する。

**作業内容**:
- [ ] 単体動作確認（Fox 1台、RTL-SDRで受信）
- [ ] 5台同時起動でスロット確認（[TESTING.md §2](TESTING.md) 参照）
- [ ] tinySAでスプリアス測定（[TESTING.md §3](TESTING.md) 参照）
- [ ] フィールドテスト（実際の競技コースで方向探知確認）
- [ ] バッテリー持続時間の実測

**依存**: Step 4・5完了後

---

## 将来の拡張 / Future

### 80m（3.5MHz）対応

**概要**: Si5351のCLK1出力を使って3.5MHz帯のARDFフォックスとして動作させる。

**検討事項**:
- Si5351 CLK1は拡張ヘッダ（J1）経由で利用可能
- 3.5MHz帯では出力レベルが低いため外部アンプが必要（例: IRF510を使ったAM/DSBアンプ）
- JARL ARDF規定では3.5MHz帯は80m部門として独立した競技
- 変調方式: AM（3.5MHz帯はAM変調が標準）← Si5351のPLL dithering方式では困難、DAC追加を検討

**参考**: Si5351 CLK1のピン番号 → 拡張ヘッダJ1のピン配置を確認すること

---

### GPS同期対応

**概要**: 1PPSシグナルを使ってすべてのフォックスを絶対時刻で同期する。現状は電源同時投入による相対同期。

**検討事項**:
- GPSモジュール（u-blox M8N等）を拡張ヘッダ経由で接続
- 1PPSパルスで `millis()` を補正 → 60秒サイクルの絶対アライメント
- 利点: 電源投入タイミングのズレを±1ms以内に補正可能
- 欠点: コスト増（GPSモジュール ≈ 1,500〜3,000円）・GPS取得まで送信遅延

---

### RTCによる自動電源制御

**概要**: 競技開始・終了時刻をあらかじめ設定し、RTC（DS3231等）で自動ON/OFFを制御する。

**検討事項**:
- DS3231はI2C接続（拡張ヘッダのI2C0を共有可能）
- 競技開始前にすべての局が送信しないよう時刻制御
- `settings.txt` に `START_TIME` / `END_TIME` を追加

---

### Webコンフィギュレータ

**概要**: USB MSCでの `settings.txt` 編集の代わりに、WebUSBまたはBLEでブラウザから設定変更できるUIを提供する。

**検討事項**:
- TinyUSBはWebUSBをサポート
- RP2040はBluetooth非搭載（外部モジュールまたはRP2040-Wへの換装が必要）
- 優先度: 低（settings.txtでも十分実用的）

---

## 完了 / Closed

- [x] `FOX_NUMBER` 設定の追加（settings.txt対応）
- [x] ARDF識別符号（MOE〜MO5）のモールスID先頭への付与
- [x] 60秒スロット制御の実装（`audioTask()` 置き換え）
- [x] ITU Zone 1・デフォルト周波数145.660MHzの設定
- [x] `BOM.md` 作成（日本の入手先付き）
- [x] `README.ja.md` 作成
- [x] `HARDWARE.md` 作成（RP2040↔DRA818V配線表）
- [x] `TESTING.md` 作成（RTL-SDR / tinySA / 5局テスト手順）
- [x] `dra818.h` / `dra818.cpp` スタブ作成
- [x] `pwm_audio.h` スタブ作成

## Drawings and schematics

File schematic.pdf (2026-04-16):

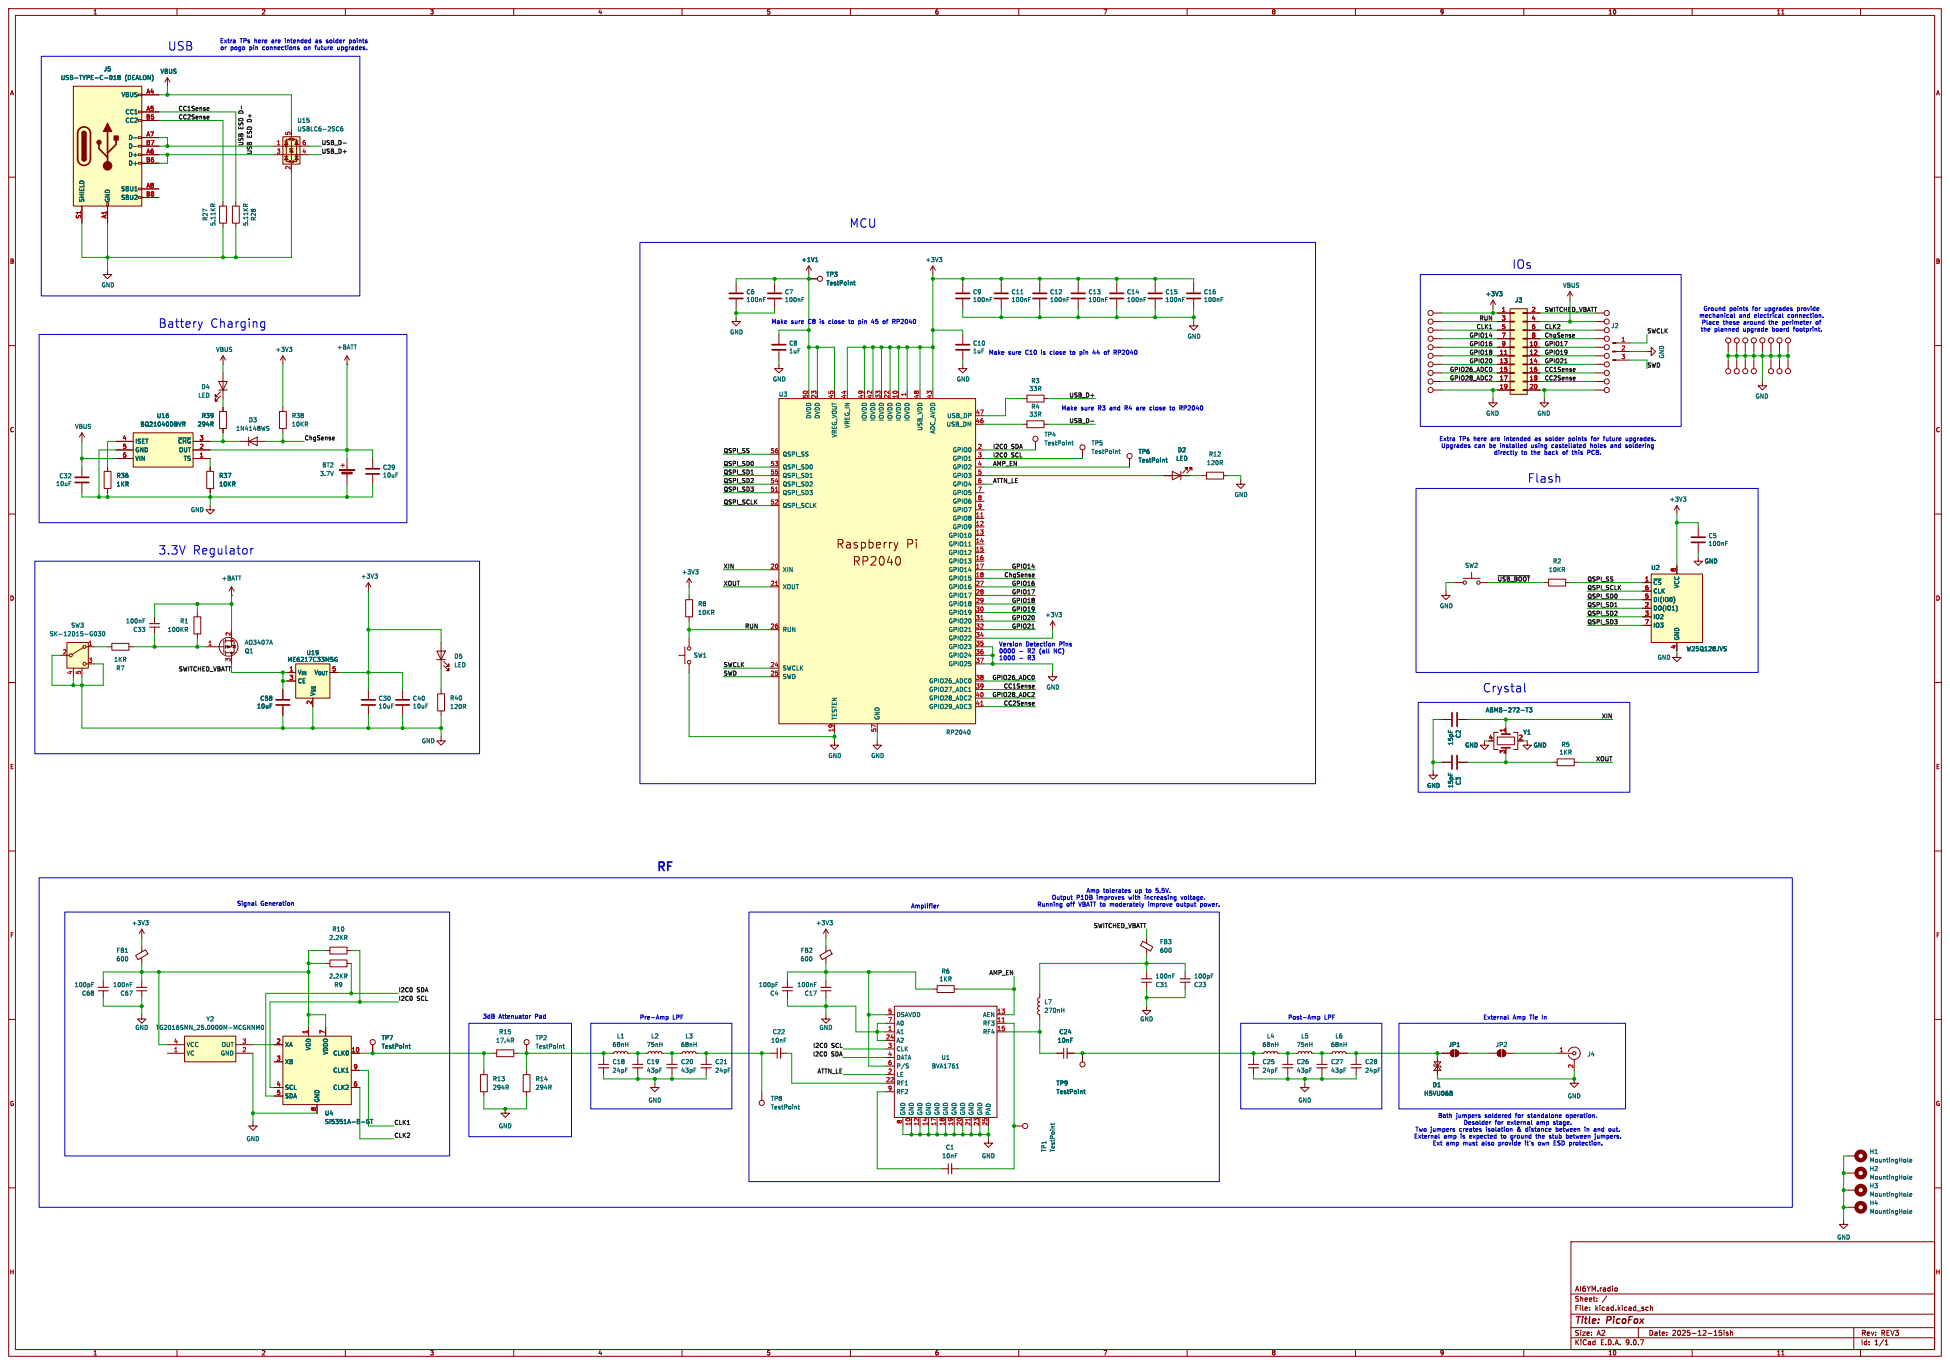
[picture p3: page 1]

the planned upgrade board footprint.

Make sure R3 and R4 are close to RP2040 Make sure C10 is close to pin 44 of RP2040
CC1Sense USB_D+ GPIO18

7 CLK0 10 CLK1 9 CLK2 6 U4Si5351A-B-GT VCC 4 VC 1 OUT 3 GND 2 Y2 TG2016SMN_25.0000M-MCGNNM0 +3V3 FB1

8 GND 10 GND 12 GND 14 GND 17 GND 18 GND 19 GND 20 GND 21 GND 23 PAD 25 AEN 13 RF3 11 RF4 15 U1 BVA1761 GND TP1 TestPoint GND

File: kicad.kicad_sch Sheet: / AI6YM.radio R13

H2 MountingHole H4 MountingHole H3 MountingHole GND

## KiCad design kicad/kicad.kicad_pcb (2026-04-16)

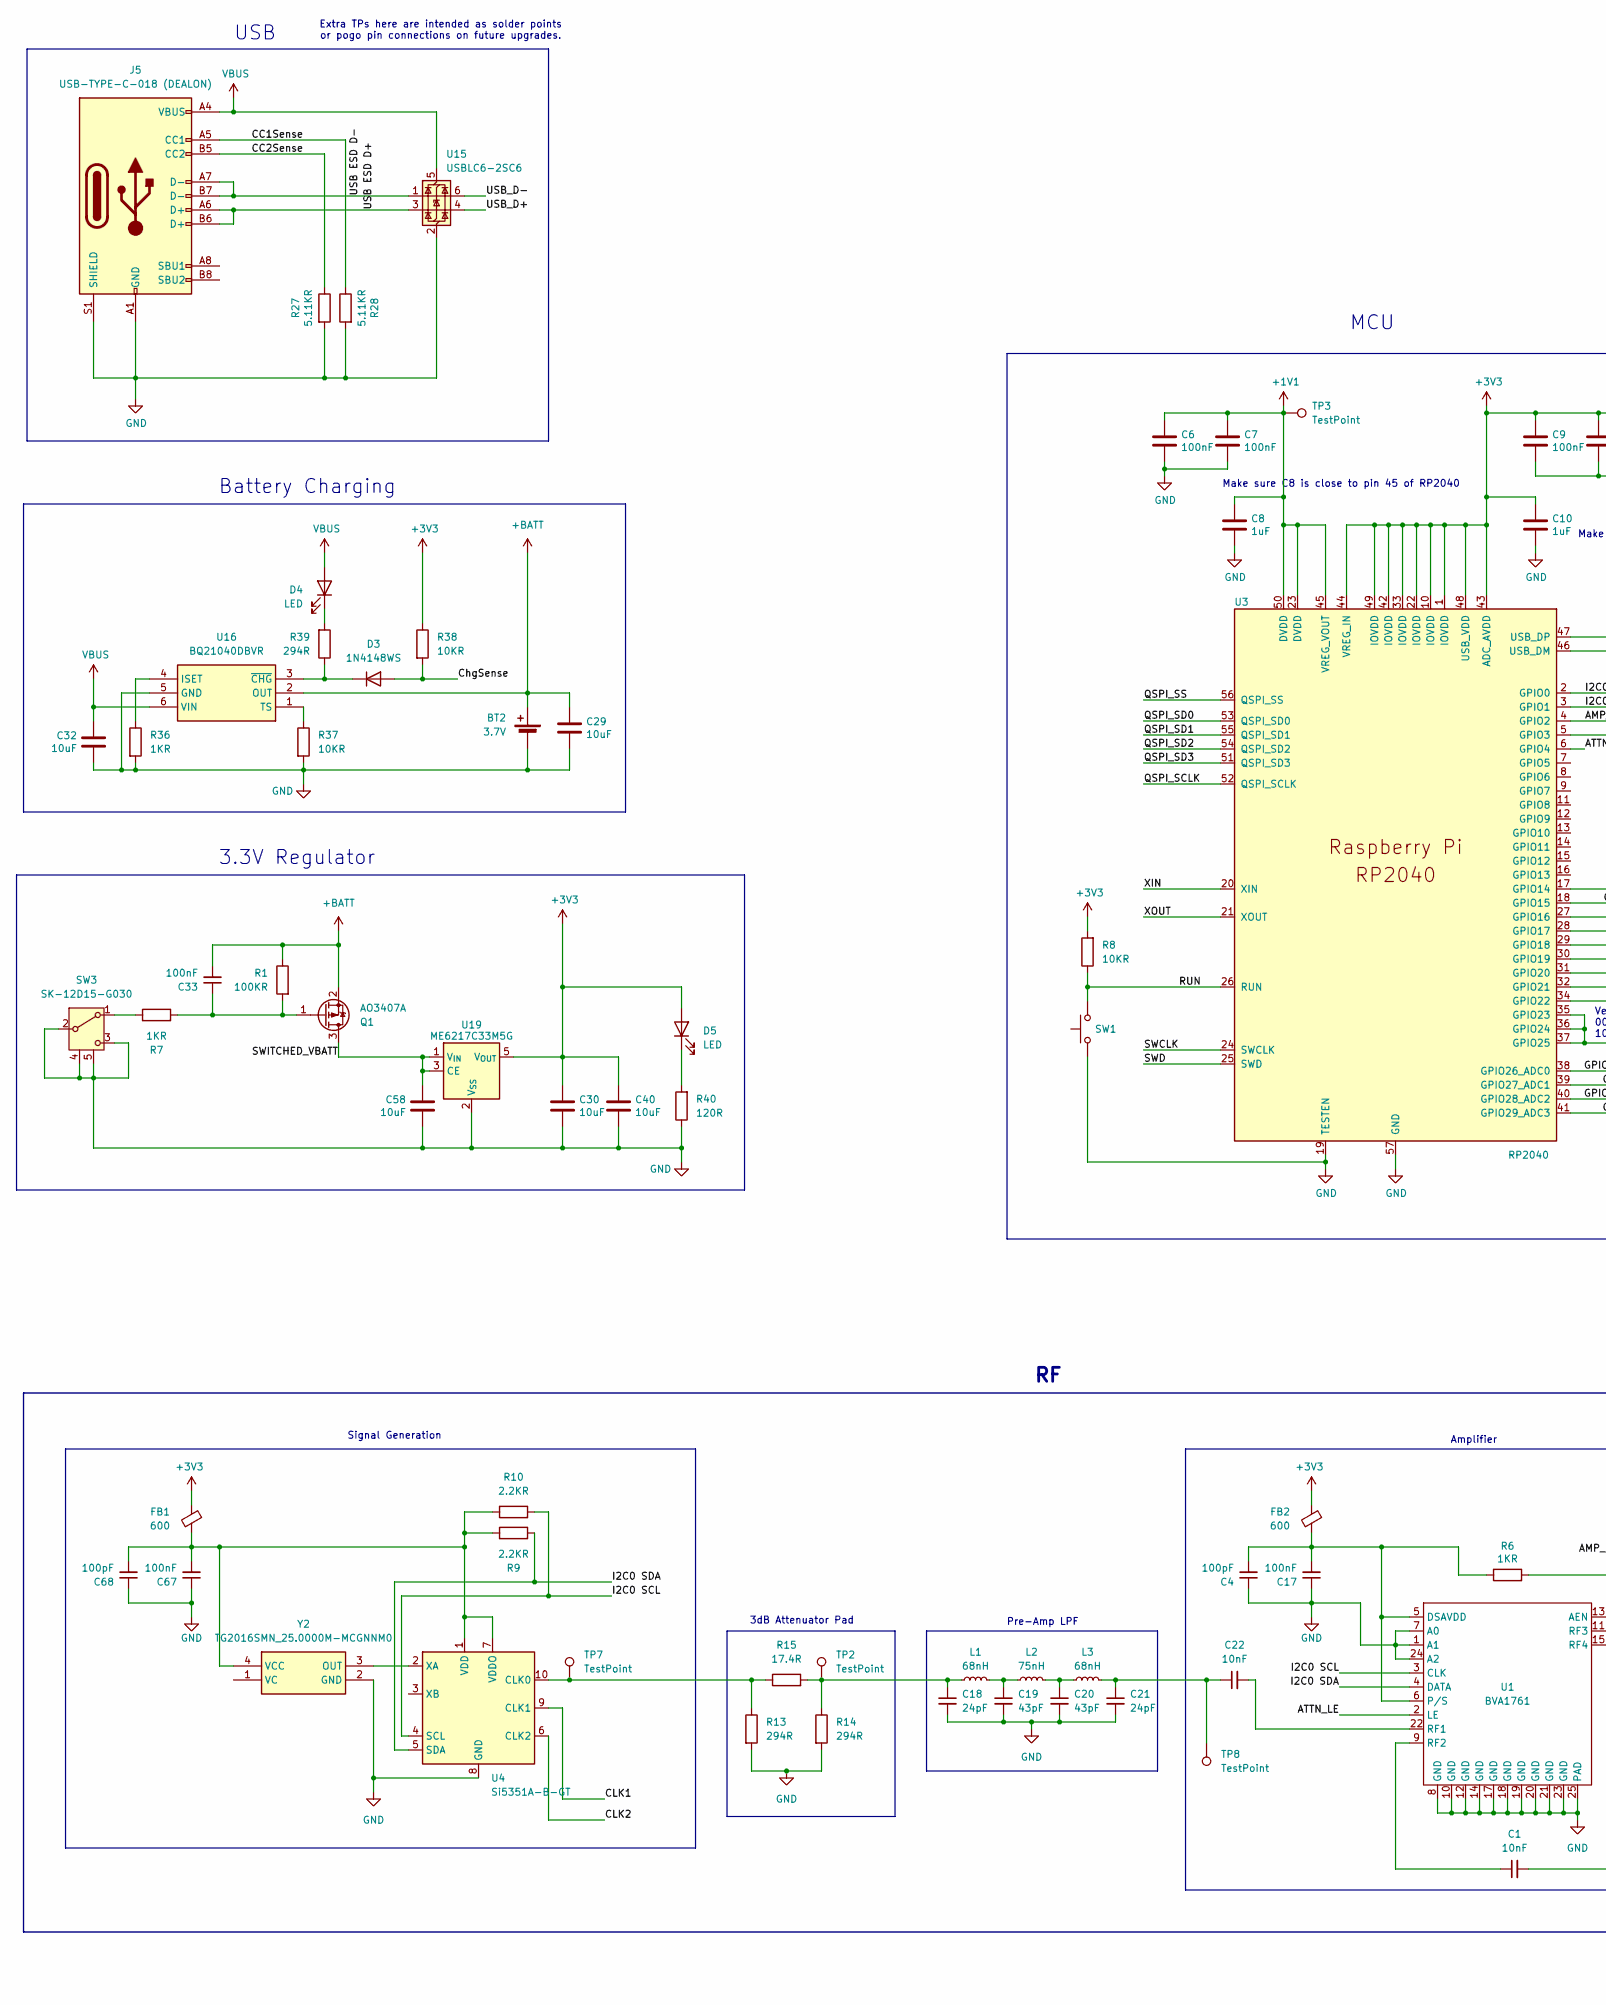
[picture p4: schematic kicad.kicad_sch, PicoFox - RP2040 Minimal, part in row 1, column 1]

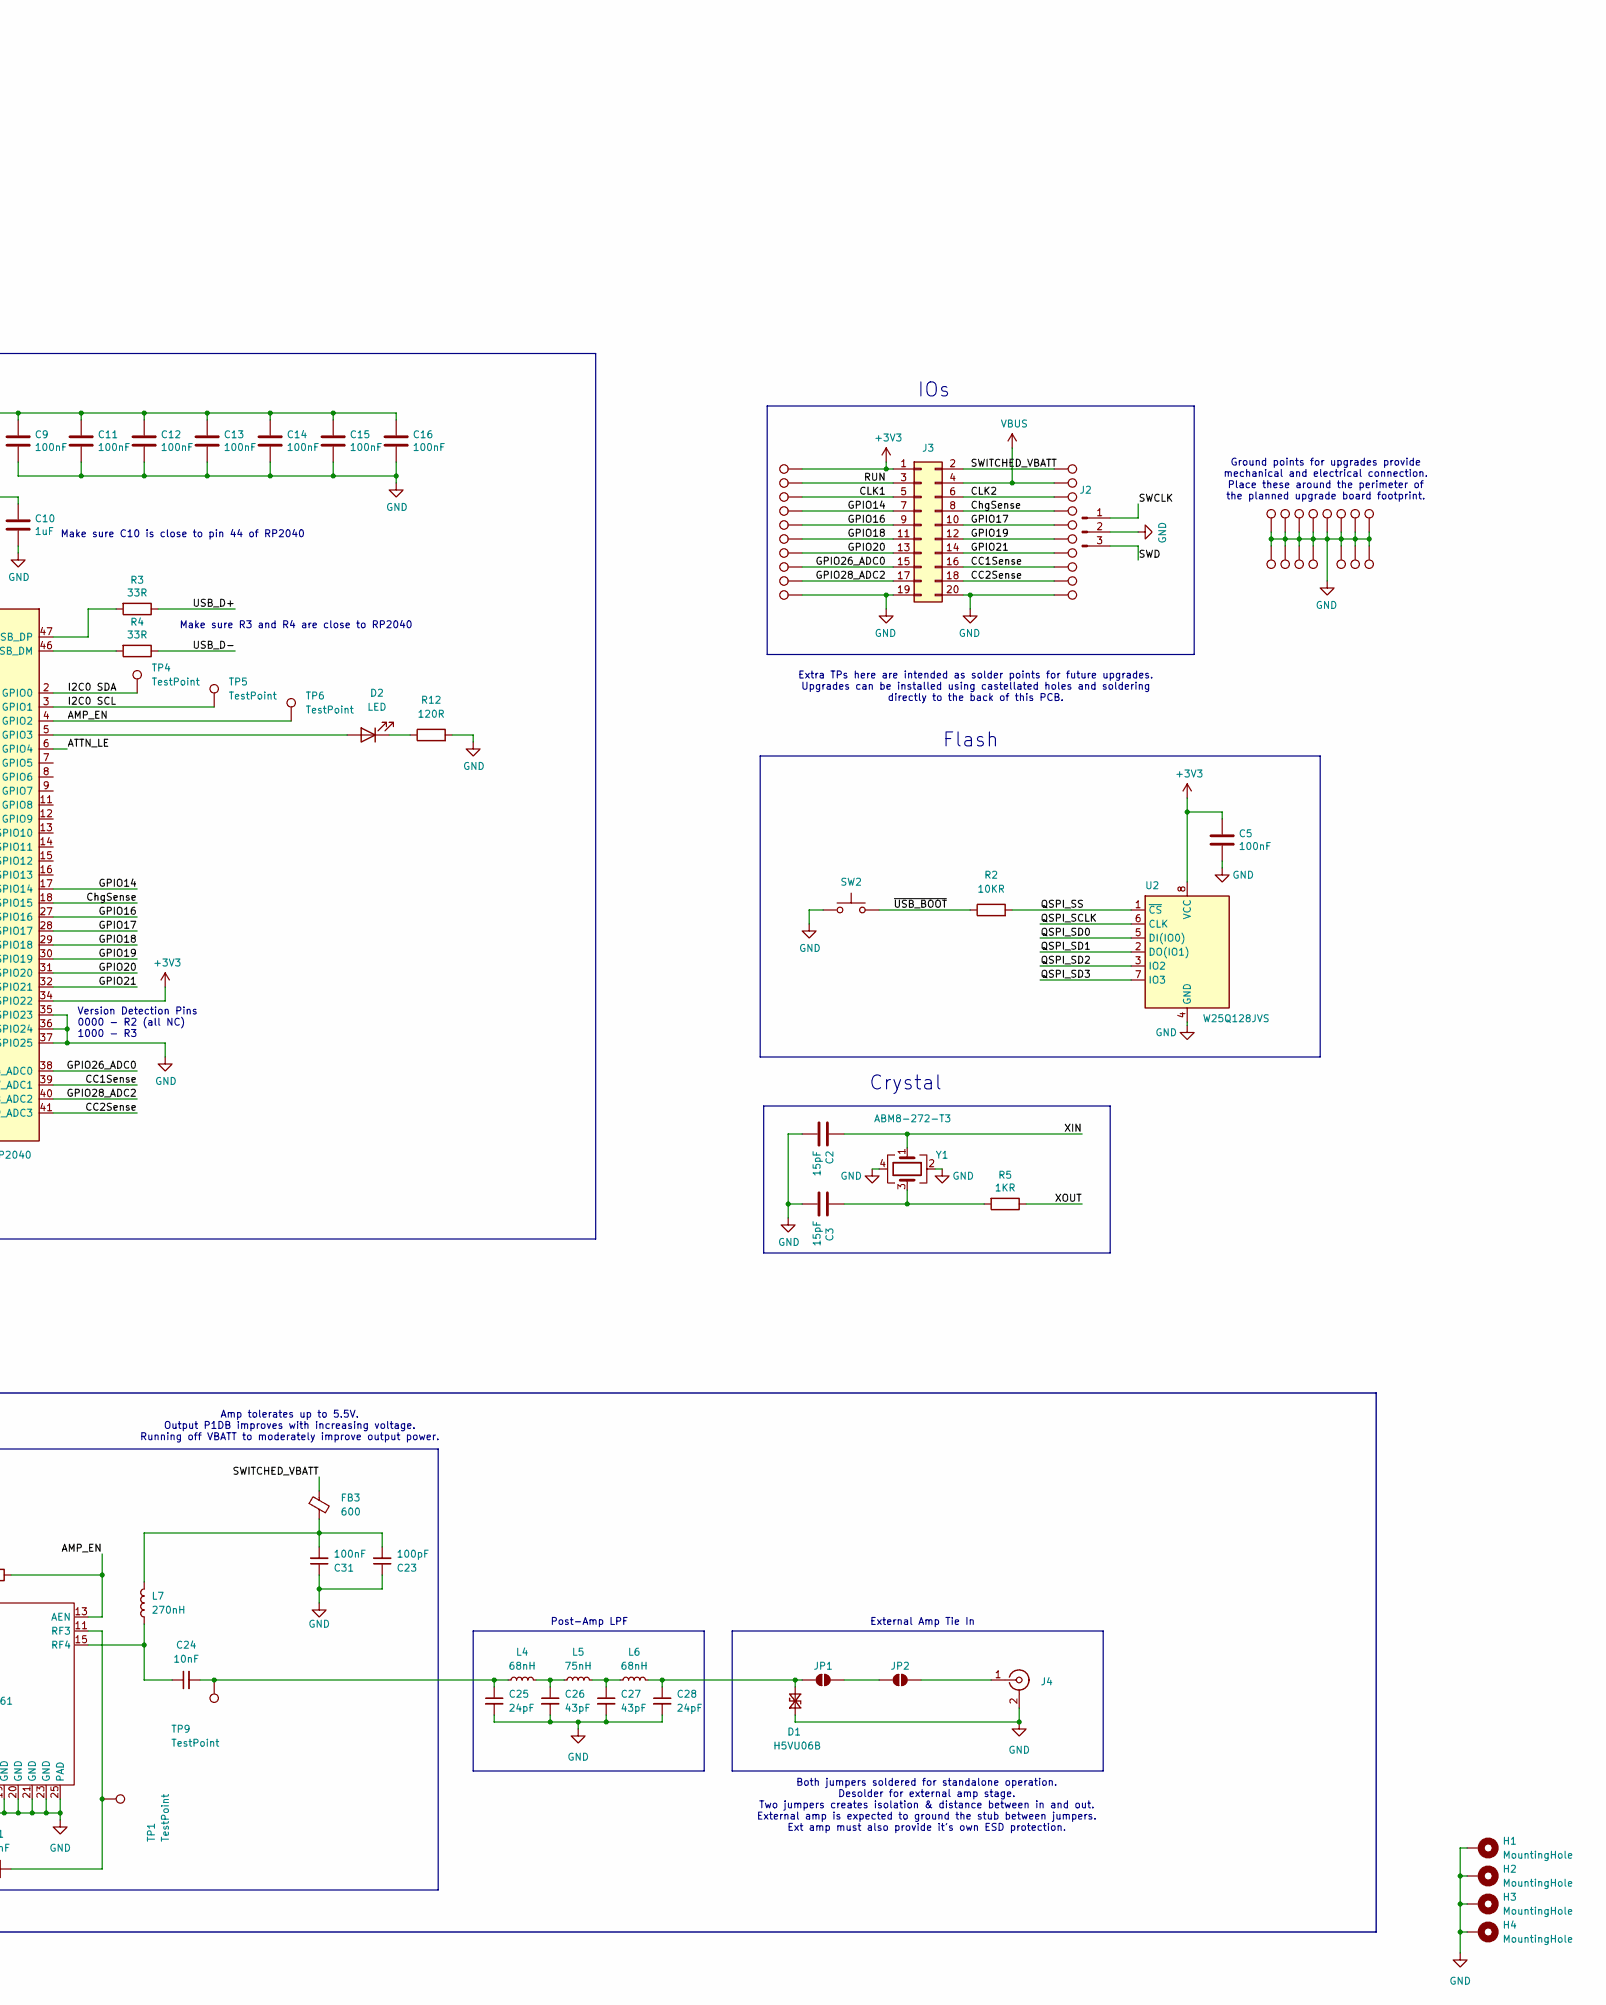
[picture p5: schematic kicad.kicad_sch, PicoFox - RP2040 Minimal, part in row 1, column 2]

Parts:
BT2: 3.7V; JST PH 2 Horizontal; LCSC C295747
C1, C22, C24: 10nF; C_0402_1005Metric; LCSC C3834692
C2, C3: 15pF; C_0402_1005Metric; LCSC C1548
C4, C23, C68: 100pF; C_0402_1005Metric; LCSC C1546
C5, C6, C7, C9, C11, C12, C13, C14, C15, C16, C17, C31, C33, C67: 100nF; C_0402_1005Metric; LCSC C307331
C8, C10: 1uF; C_0402_1005Metric; LCSC C52923
C18, C21, C25, C28: 24pF; C_0402_1005Metric; LCSC C1864480
C19, C20, C26, C27: 43pF; C_0402_1005Metric; LCSC C415393
C29, C30, C32, C40, C58: 10uF; C_0603_1608Metric; LCSC C96446
D1: H5VU06B; DFN0603-2L; LCSC C20615780
D2, D4, D5: LED; LED 1206 Side View; LCSC C375479
D3: 1N4148WS; D_SOD-323; LCSC C2128
FB1, FB2, FB3: 600; L_0402_1005Metric; LCSC C76886
H1, H2, H3, H4: MountingHole; MountingHole_2.7mm_M2.5_Pad
J2: Conn_01x03_Pin; JST_SH_SM03B-SRSS-TB_1x03-1MP_P1.00mm_Horizontal; LCSC C160403
J3: Conn_02x10_Counter_Clockwise; PinHeader_2x10_P2.54mm_Vertical_SMD; LCSC C3294468
J4: Conn_Coaxial_Small; SMA_Samtec_SMA-J-P-H-ST-EM1_EdgeMount; LCSC C5301850
J5: USB-TYPE-C-018 (DEALON); USB_C_Receptacle_HCTL_HC-TYPE-C-16P-01A; LCSC C2927038
JP1, JP2: SolderJumper_2_Open; SolderJumper-2_P1.3mm_Open_RoundedPad1.0x1.5mm
L1, L3, L4, L6: 68nH; L_0402_1005Metric; LCSC C7427064
L2, L5: 75nH; L_0402_1005Metric
L7: 270nH; L_0402_1005Metric; LCSC C22400372
Q1: AO3407A; SOT-23; LCSC C7436553
R1: 100KR; R_0402_1005Metric; LCSC C25741
R2, R8, R37, R38: 10KR; R_0402_1005Metric; LCSC C25744
R3, R4: 33R; R_0402_1005Metric; LCSC C25105
R5, R6, R7, R36: 1KR; R_0402_1005Metric; LCSC C11702
R9, R10: 2.2KR; R_0402_1005Metric; LCSC C25879
R12, R40: 120R; R_0402_1005Metric; LCSC C25079
R13, R14, R39: 294R; R_0402_1005Metric; LCSC C852689
R15: 17.4R; R_0402_1005Metric; LCSC C284383
R27, R28: 5.11KR; R_0402_1005Metric; LCSC C5126228
SW1, SW2: SW_Push_SPST_NO_Alps_SKRK; LCSC C720477
SW3: SK-12D15-G030; SW_Slide_SPDT_Angled_CK_OS102011MA1Q; LCSC C7544904
TP1, TP2, TP3, TP4, TP5, TP6, TP7, TP8, TP9: TestPoint; TestPoint_Pad_D1.0mm
TP14, TP17, TP19, TP20, TP21, TP22, TP23, TP24, TP25, TP26, TP27, TP28, TP29, TP30, TP31, TP32, TP33, TP34, TP35, TP36, TP37, TP38, TP39, TP40, TP41, TP42, TP43, TP44, TP45, TP46, TP47, TP48, TP49, TP51, TP53: TestPoint; Castellation Pad
U1: BVA1761; QFN-24-1EP_4x4mm_P0.5mm_EP2.5x2.5mm; LCSC C38240054
U2: W25Q128JVS; SOIC-8_5.23x5.23mm_P1.27mm; LCSC C97521
U3: RP2040; RP2040-QFN-56; LCSC C2040
U4: Si5351A-B-GT; MSOP-10_3x3mm_P0.5mm; LCSC C504891
U15: USBLC6-2SC6; SOT-23-6; LCSC C5180249
U16: BQ21040DBVR; SOT95P280X145-6N; Mouser Part Number 595-BQ21040DBVR
U19: ME6217C33M5G; SOT-23-5; LCSC C427602
Y1: ABM8-272-T3; Crystal_SMD_3225-4Pin_3.2x2.5mm; LCSC C20625731
Y2: TG2016SMN_25.0000M-MCGNNM0; TG2016SMN250000MMCGNNM0; Mouser Part Number 732-2016SMN25MCGNNM0

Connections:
+1V1: C6.1, C7.1, C8.1, TP3.1, U3.23 (DVDD), U3.45 (VREG_VOUT), U3.50 (DVDD)
+3V3: C5.1, C9.1, C10.1, C11.1, C12.1, C13.1, C14.1, C15.1, C16.1, C30.1, C40.1, D5.1 (A), FB1.1, FB2.1, J3.1, R8.2, R38.1, TP14.1, U2.8 (VCC), U3.1 (IOVDD), U3.10 (IOVDD), U3.22 (IOVDD), U3.33 (IOVDD), U3.34 (GPIO22), U3.42 (IOVDD), U3.43 (ADC_AVDD), U3.44 (VREG_IN), U3.48 (USB_VDD), U3.49 (IOVDD), U19.5 (V_{OUT})
+BATT: BT2.1 (+), C29.1, C33.2, Q1.2 (S), R1.1, U16.2 (OUT)
/AMP_EN: R6.1, TP6.1, U1.13 (AEN), U3.4 (GPIO2)
/ATTN_LE: U1.2 (LE), U3.6 (GPIO4)
/CC1Sense: J3.16, J5.A5 (CC1), R28.1, TP29.1, U3.39 (GPIO27_ADC1)
/CC2Sense: J3.18, J5.B5 (CC2), R27.1, TP28.1, U3.41 (GPIO29_ADC3)
/CLK1: J3.5, TP19.1, U4.9 (CLK1)
/CLK2: J3.6, TP34.1, U4.6 (CLK2)
/ChgSense: D3.2 (A), J3.8, R38.2, TP33.1, U3.18 (GPIO15)
/GPIO14: J3.7, TP20.1, U3.17 (GPIO14)
/GPIO16: J3.9, TP21.1, U3.27 (GPIO16)
/GPIO17: J3.10, TP32.1, U3.28 (GPIO17)
/GPIO18: J3.11, TP22.1, U3.29 (GPIO18)
/GPIO19: J3.12, TP31.1, U3.30 (GPIO19)
/GPIO20: J3.13, TP23.1, U3.31 (GPIO20)
/GPIO21: J3.14, TP30.1, U3.32 (GPIO21)
/GPIO26_ADC0: J3.15, TP26.1, U3.38 (GPIO26_ADC0)
/GPIO28_ADC2: J3.17, TP25.1, U3.40 (GPIO28_ADC2)
/I2C0 SCL: R10.1, TP5.1, U1.3 (CLK), U3.3 (GPIO1), U4.4 (SCL)
/I2C0 SDA: R9.1, TP4.1, U1.4 (DATA), U3.2 (GPIO0), U4.5 (SDA)
/QSPI_SCLK: U2.6 (CLK), U3.52 (QSPI_SCLK)
/QSPI_SD0: U2.5 (DI(IO0)), U3.53 (QSPI_SD0)
/QSPI_SD1: U2.2 (DO(IO1)), U3.55 (QSPI_SD1)
/QSPI_SD2: U2.3 (IO2), U3.54 (QSPI_SD2)
/QSPI_SD3: U2.7 (IO3), U3.51 (QSPI_SD3)
/QSPI_SS: R2.2, U2.1 (~CS), U3.56 (QSPI_SS)
/RUN: J3.3, R8.1, SW1.2, TP17.1, U3.26 (RUN)
/SWCLK: J2.1, U3.24 (SWCLK)
/SWD: J2.3, U3.25 (SWD)
/SWITCHED_VBATT: C58.1, FB3.1, J3.2, Q1.3 (D), TP36.1, U19.1 (V_{IN}), U19.3 (CE)
/USB ESD D+: J5.A6 (D+), J5.B6 (D+), U15.3 (I/O2)
/USB ESD D-: J5.A7 (D-), J5.B7 (D-), U15.1 (I/O1)
/USB_D+: R3.1, U15.4 (I/O2)
/USB_D-: R4.1, U15.6 (I/O1)
/XIN: C2.1, U3.20 (XIN), Y1.1
/XOUT: R5.1, U3.21 (XOUT)
/~USB_BOOT: R2.1, SW2.2
GND: BT2.2 (-), C2.2, C3.2, C4.1, C5.2, C6.2, C7.2, C8.2, C9.2, C10.2, C11.2, C12.2, C13.2, C14.2, C15.2, C16.2, C17.1, C18.2, C19.2, C20.2, C21.2, C23.1, C25.2, C26.2, C27.2, C28.2, C29.2, C30.2, C31.1, C32.2, C40.2, C58.2, C67.1, C68.1, D1.1 (A1), H1.1, H2.1, H3.1, H4.1, J2.2, J3.19, J3.20, J4.2 (Ext), J5.A1 (GND), J5.A12 (GND), J5.B1 (GND), J5.B12 (GND), J5.S1 (SHIELD), R12.2, R13.2, R14.2, R27.2, R28.2, R36.2, R37.2, R40.1, SW1.1, SW2.1, SW3.2 (B), SW3.3 (C), SW3.4 (SH), SW3.5 (SH), TP24.1, TP27.1, TP37.1, TP38.1, TP39.1, TP40.1, TP41.1, TP42.1, TP43.1, TP44.1, TP45.1, TP46.1, TP47.1, TP48.1, TP49.1, TP51.1, TP53.1, U1.1 (A1), U1.7 (A0), U1.8 (GND), U1.10 (GND), U1.12 (GND), U1.14 (GND), U1.17 (GND), U1.18 (GND), U1.19 (GND), U1.20 (GND), U1.21 (GND), U1.23 (GND), U1.24 (A2), U1.25 (PAD), U2.4 (GND), U3.19 (TESTEN), U3.35 (GPIO23), U3.36 (GPIO24), U3.37 (GPIO25), U3.57 (GND), U4.8 (GND), U15.2 (GND), U16.5 (GND), U19.2 (V_{SS}), Y1.2, Y1.4, Y2.2 (GND)
unnamed: C3.1, R5.2, Y1.3
unnamed: C18.1, L1.1, R14.1, R15.2, TP2.1
unnamed: C19.1, L1.2, L2.1
unnamed: C20.1, L2.2, L3.1
unnamed: C21.1, C22.1, L3.2, TP8.1
unnamed: C23.2, C31.2, FB3.2, L7.2
unnamed: C24.2, C25.1, L4.1, TP9.1
unnamed: C26.1, L4.2, L5.1
unnamed: C27.1, L5.2, L6.1
unnamed: C28.1, D1.2 (A2), JP1.1 (A), L6.2
unnamed: D2.1 (A), U3.5 (GPIO3)
unnamed: D2.2 (K), R12.1
unnamed: D3.1 (K), R39.1, U16.3 (~CHG)
unnamed: D4.2 (K), R39.2
unnamed: D5.2 (K), R40.2
unnamed: J4.1 (In), JP2.2 (B)
unnamed: JP1.2 (B), JP2.1 (A)
unnamed: C33.1, Q1.1 (G), R1.2, R7.1
unnamed: R7.2, SW3.1 (A)
unnamed: C4.2, C17.2, FB2.2, R6.2, U1.5 (DSAVDD), U1.6 (P/S)
unnamed: C22.2, U1.22 (RF1)
unnamed: C1.1, U1.9 (RF2)
unnamed: C1.2, TP1.1, U1.11 (RF3)
unnamed: C24.1, L7.1, U1.15 (RF4)
unnamed: R4.2, U3.46 (USB_DM)
unnamed: R3.2, U3.47 (USB_DP)
unnamed: R13.1, R15.1, TP7.1, U4.10 (CLK0)
unnamed: C67.2, C68.2, FB1.2, R9.2, R10.2, U4.1 (VDD), U4.7 (VDDO), Y2.4 (VCC)
unnamed: U4.2 (XA), Y2.3 (OUT)
unnamed: R36.1, U16.4 (ISET)
unnamed: R37.1, U16.1 (TS)
VBUS: C32.1, D4.1 (A), J3.4, J5.A4 (VBUS), J5.A9 (VBUS), J5.B4 (VBUS), J5.B9 (VBUS), TP35.1, U15.5 (VBUS), U16.6 (VIN)

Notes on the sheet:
Extra TPs here are intended as solder points or pogo pin connections on future upgrades.
IOs
External Amp Tie In
Amplifier
Extra TPs here are intended as solder points for future upgrades. Upgrades can be installed using castellated holes and soldering directly to the back of this PCB.
Battery Charging
Make sure C8 is close to pin 45 of RP2040
Ground points for upgrades provide mechanical and electrical connection. Place these around the perimeter of the planned upgrade board footprint.
3.3V Regulator
Crystal
Pre-Amp LPF
Version Detection Pins 0000 - R2 (all NC) 1000 - R3
Both jumpers soldered for standalone operation. Desolder for external amp stage. Two jumpers creates isolation & distance between in and out. External amp is expected to ground the stub between jumpers. Ext amp must also provide it's own ESD protection.
Make sure C10 is close to pin 44 of RP2040
Post-Amp LPF
Amp tolerates up to 5.5V. Output P1DB improves with increasing voltage. Running off VBATT to moderately improve output power.
Signal Generation
USB
Make sure R3 and R4 are close to RP2040
Flash
3dB Attenuator Pad
MCU

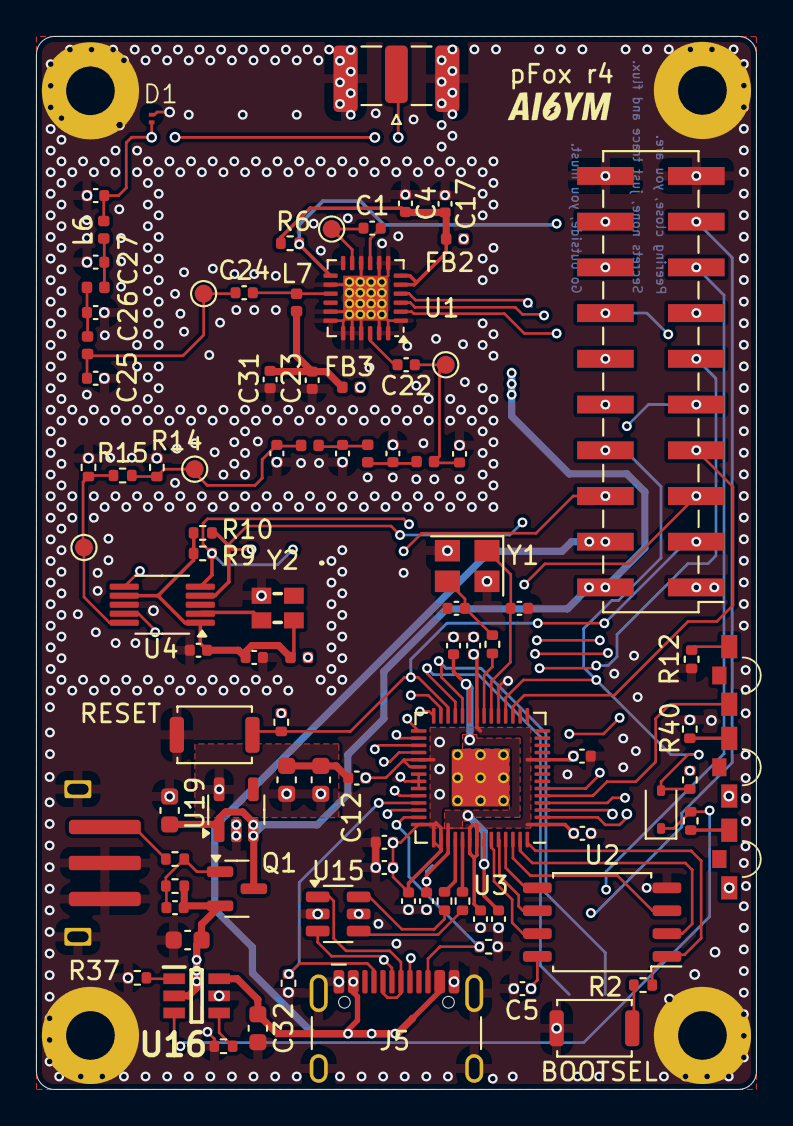
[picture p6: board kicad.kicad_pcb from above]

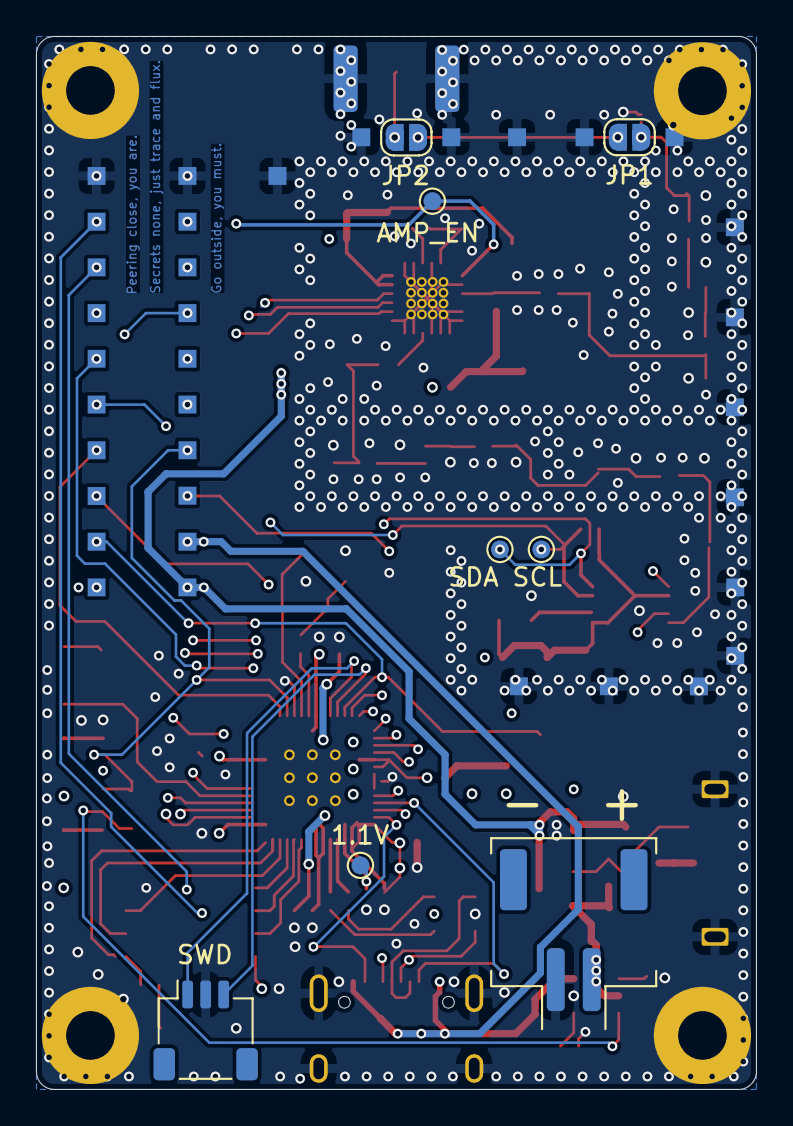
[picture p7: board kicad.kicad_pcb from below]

Board: 4 copper layers, 40.0 x 58.5 mm, 141 parts (43 on the bottom side), 71 nets.

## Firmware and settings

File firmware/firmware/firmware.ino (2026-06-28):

/* PicoFox - 2M FM Fox Transmitter

Copyright 2025 Giorgi Enterprises LLC dba AI6YM.radio.
License: Creative Commons Attribution-NonCommercial-ShareAlike 4.0 International (see LICENSE file).

COMMERCIAL USE OF THIS CODE AND ANY DERIVATIVE IS FORBIDDEN WITHOUT PERMISSION FROM THE COPYRIGHT HOLDER!

You may configure this software without compiling and flashing. Simply connect the device to your PC with a USB cable and edit the
settings.txt file. You may also change the audio which is played between morse code IDs by replacing the audio.wav file. The file you
provide MUST be 5kHz sampling, unsigned 16bit PCM audio.

The device may be reset to factory settings by deleting the settings.txt and audio.wav files. In factory settings the device WILL NOT
transmit. Configuring a callsign is required to enable the transmitter.
*/

#include <Arduino.h>
#include <Wire.h>
#include <si5351.h>
#include "SPI.h"
#include "SdFat_Adafruit_Fork.h"
#include "Adafruit_SPIFlash.h"
#include "Adafruit_TinyUSB.h"

#include "audio.h"

// #define DEBUG 1

// Board revision ID pins.
// Pulldown required. 0000 == r2, 1000 == r3.
#define ID0 22u
#define ID1 23u
#define ID2 24u
#define ID3 25u

#define SDA 0u                                  // I2C data pin.
#define SCL 1u                                  // I2C clock pin.
#define AMP_EN 2u                               // Pin which enables the amplifier. Set LOW to enable, HIGH to disable.
#define ATTN_LE 4u                              // Pin which latches the attenuator.
#define AUDIO_SAMPLE_RATE_HZ 5000               // Audio sample rate (also rate of updates to SI5351).
#define FM_DEVIATION_HZ 10000                   // Maximum RF deviation in Hz.
#define SI5351_PLL SI5351_PLLA                  // PLL which will be used on the SI5351, consider this PLL unavailable for other purposes.
#define SI5351_CLOCK_OUTPUT SI5351_CLK0         // Clock output which drives RF circuitry.
#define SI5351_PLL_HZ 900000000                 // PLL frequency in Hz.
#define SI5351_MS_MAX_DENOM 1048575             // 2^20 - 1, max denominator for fractional MS divider.
#define SI5351_MS_RATIONAL_CALC_ITERS 16        // Maximum iterations searching for MS parameters, keeps calculation within 200us.

#define SI5351_CLOCK_PARAM_START 42             // Register address on which multisynth parameters start.
#define SI5351_CLOCK_DIV 6                      // Fixed divider between PLL clock and MS.
#define SI5351_DRIVE_LEVEL_R2 SI5351_DRIVE_2MA  // Power output from SI5351, higher levels don't add much output but do create spurious emmissions.
#define SI5351_DRIVE_LEVEL_R3 SI5351_DRIVE_2MA  // Power output from SI5351.
#define SAMPLE_WRITE_CORR_US -3                 // Time correction between sample writes to account for code which can't be measured.
#define MAX_UINT32 4294967295                   // Maximum value for a 32 bit unsigned integer. Used to prevent glitches when micros() overflows.

#define TEST_MODE_PIN 14u                       // Pin which is monitored to enter test mode. If you use this pin feel free to remove this logic.
#define SYNC_PIN      13u                       // Sync input (active LOW pulse). Resets the 60s cycle epoch. See HARDWARE.md.

// Frequency limitations.
#define MIN_FREQ_MHZ 144
#define MAX_FREQ_MHZ_ITU1 146  // ITU zone 1.
#define MAX_FREQ_MHZ 148       // ITU zones 2 and 3.

// Test mode detected. Indicates program / test before shipping.
bool test_mode;

// Timestamp of the last sync pulse (millis()). Resets the 60s cycle epoch.
// Zero means power-on is used as the epoch (same as no sync).
volatile uint32_t syncEpochMs = 0;

// Board revision.
uint16_t revision;

// RF Clock Gen
Si5351 si5351;

// Uses same external flash chip that the RP2040 is executing from. Size depends on Tools -> Flash Size setting.
Adafruit_FlashTransport_RP2040 flashTransport;
Adafruit_SPIFlash flash(&flashTransport);

// Filesystem and file descriptors.
FatFormatter formatter;
FatVolume fatfs;
FatFile root;
FatFile file;

// Controller for USB mass storage device.
Adafruit_USBD_MSC usb_msc;
bool hostMounted = false;

// Flash file names.
const char SETTINGS_TXT[] = "settings.txt";
const char AUDIO_WAV[] = "audio.wav";
const char CALLSIGN_WAV[] = ".callsign.wav";
const char SETTINGS_CRC[] = ".settings_crc.bin";

// Default settings.
const char DEFAULT_CALLSIGN[12] = "";
const uint8_t DEFAULT_ITU_ZONE = 1;
// Japan ARDF frequencies: 145.660 MHz or 145.780 MHz (JARL)
const double DEFAULT_FREQ_MHZ = 145.660;
const uint8_t DEFAULT_DUTY_CYCLE = 100;
const uint8_t DEFAULT_WPM = 15;
const uint8_t DEFAULT_FARNSWORTH_WPM = 10;
const uint16_t DEFAULT_MORSE_TONE_HZ = 600;
const uint8_t DEFAULT_TONE_AMPLITUDE_PERCENT = 70;
const uint8_t DEFAULT_ATTENUATION = 0;
const uint8_t DEFAULT_FOX_NUMBER = 1;

// Config struct, start by loading defaults.
struct Settings {
  char callsign[12];
  uint8_t ituZone;
  double transmitFreqMHz;
  uint8_t dutyCyclePercent;
  uint8_t morseWPM;
  uint8_t farnsworthWPM;
  uint16_t morseToneHz;
  uint8_t toneAmplitudePercent;
  bool isConfigured;
  uint8_t attenuation;
  uint8_t foxNumber;  // ARDF fox number 1-5 (MOE=1, MOI=2, MOS=3, MOH=4, MO5=5)
};

Settings settings = {
  .callsign = { *DEFAULT_CALLSIGN },
  .ituZone = DEFAULT_ITU_ZONE,
  .transmitFreqMHz = DEFAULT_FREQ_MHZ,
  .dutyCyclePercent = DEFAULT_DUTY_CYCLE,
  .morseWPM = DEFAULT_WPM,
  .farnsworthWPM = DEFAULT_FARNSWORTH_WPM,
  .morseToneHz = DEFAULT_MORSE_TONE_HZ,
  .isConfigured = (strlen(DEFAULT_CALLSIGN) > 0),
  .attenuation = DEFAULT_ATTENUATION,
  .foxNumber = DEFAULT_FOX_NUMBER
};

int settingsCrc = 0;

struct MsABC {
  uint32_t A;
  uint32_t B;
  uint32_t C;
  Si5351RegSet reg;
  uint8_t int_mode;
};

// Creates a fat16 filesystem in the flash space.
void formatFat16(void) {
  uint8_t workbuf[4096];
  formatter.format(&flash, workbuf);
  if (fatfs.begin(&flash, true, 1, 0)) {
    Serial.println("Flash chip successfully formatted with new empty filesystem!");
  } else {
    Serial.println("Formatting failed. Good luck friend.");
    while (true)
      ;
  }
}

// Reads data from flash device.
int32_t mscReadCb(uint32_t lba, void* buffer, uint32_t bufsize) {
  return flash.readBlocks(lba, (uint8_t*)buffer, bufsize / 512) ? bufsize : -1;
}

// Writes data to the flash device.
int32_t mscWriteCb(uint32_t lba, uint8_t* buffer, uint32_t bufsize) {
  hostMounted = true;
  return flash.writeBlocks(lba, buffer, bufsize / 512) ? bufsize : -1;
}

// Flushes writes to flash.
void mscFlushCb(void) {
  flash.syncBlocks();
}

bool openRoot() {
  return root.openRoot(&fatfs);
}

void closeRoot() {
  root.close();
}

// Removes files which shouldn't be present and applies defaults for missing files.
void flashCleanup() {
  // Open root filesystem.
  if (!openRoot()) {
    Serial.println("failed to open rootfs");
  }

  // Write the default settings if settings file is missing.
  if (!root.exists(SETTINGS_TXT)) {
    saveDefaultSettings();
    Serial.println("No settings file found. Writing default settings.");
  }

  // Write the default audio if audio file is missing.
  if (!root.exists(AUDIO_WAV)) {
    saveDefaultAudio();
    Serial.println("No audio file found. Writing default audio.");
  }

  // Close the filesytem.
  closeRoot();
}

// Saves the default settings struct to the settings.txt file in flash.
void saveDefaultSettings() {
  char buffer[512];
  snprintf(
    buffer,
    sizeof(buffer),
    "CALLSIGN=%s\nITU_ZONE=%u\nFREQ_MHZ=%.6f\nDUTY_CYCLE=%u\nATTENUATION=%u\nMORSE_WPM=%u\nMORSE_FARNSWORTH_WPM=%u\nMORSE_TONE=%u\nMORSE_TONE_VOL=%u\nFOX_NUMBER=%u\n",
    DEFAULT_CALLSIGN,
    DEFAULT_ITU_ZONE,
    DEFAULT_FREQ_MHZ,
    DEFAULT_DUTY_CYCLE,
    DEFAULT_ATTENUATION,
    DEFAULT_WPM,
    DEFAULT_FARNSWORTH_WPM,
    DEFAULT_MORSE_TONE_HZ,
    DEFAULT_TONE_AMPLITUDE_PERCENT,
    DEFAULT_FOX_NUMBER);
  file.open(&root, SETTINGS_TXT, O_RDWR | O_CREAT);
  file.write(buffer, strlen(buffer));
  file.close();
}

// Saves the default audio wav to the audio.wav file in flash.
void saveDefaultAudio() {
  file.open(&root, AUDIO_WAV, O_RDWR | O_CREAT);
  file.write(wavHeader, sizeof(wavHeader));  // Write wav header once.
  // Loop default audio to produce longer playback between IDs and transmitter cycling.
  for (int i = 0; i < DEFAULT_AUDIO_LOOPS; i++) {
    file.write(defaultAudio, sizeof(defaultAudio));
  }
  file.close();
}

// Loads the settings.txt file in flash into a settings struct.
void loadSettings() {
  openRoot();
  if (!file.open(&root, SETTINGS_TXT, O_RDONLY)) {
    Serial.println("Failed to open settings.txt");
    return;
  }

  String line = "";
  int c;
  settingsCrc = 0;
  while ((c = file.read()) >= 0) {
    settingsCrc += c;
    char ch = (char)c;
    ch = toupper(ch);
    if (ch == '\n') {
      int sep = line.indexOf('=');
      if (sep == -1) continue;
      String key = line.substring(0, sep);
      String val = line.substring(sep + 1);
      if (key == "CALLSIGN") strncpy(settings.callsign, val.c_str(), sizeof(settings.callsign) - 1);
      else if (key == "ITU_ZONE") settings.ituZone = val.toInt();
      else if (key == "FREQ_MHZ") settings.transmitFreqMHz = val.toDouble();
      else if (key == "DUTY_CYCLE") settings.dutyCyclePercent = val.toInt();
      else if (key == "ATTENUATION") settings.attenuation = val.toInt();
      else if (key == "MORSE_WPM") settings.morseWPM = val.toInt();
      else if (key == "MORSE_FARNSWORTH_WPM") settings.farnsworthWPM = val.toInt();
      else if (key == "MORSE_TONE") settings.morseToneHz = val.toInt();
      else if (key == "MORSE_TONE_VOL") settings.toneAmplitudePercent = val.toInt();
      else if (key == "FOX_NUMBER") settings.foxNumber = val.toInt();
      line = "";
    } else {
      line += ch;
    }
  }
  file.close();
  closeRoot();

  // Validate config and apply defaults when config is weird.
  if (settings.dutyCyclePercent > 100) {
    settings.dutyCyclePercent = DEFAULT_DUTY_CYCLE;
  }
  if (settings.attenuation < 0) {
    settings.attenuation = 0;
  } else if (settings.attenuation > 127) {
    settings.attenuation = 127;
  }
  if (settings.morseWPM == 0 || settings.morseWPM > 30) {
    settings.morseWPM = DEFAULT_WPM;
  }
  if (settings.farnsworthWPM == 0 || settings.farnsworthWPM < settings.morseWPM) {
    settings.farnsworthWPM = settings.morseWPM;
  }
  if (settings.morseToneHz < 100 || settings.morseToneHz >= 2500) {
    settings.morseToneHz = DEFAULT_MORSE_TONE_HZ;
  }
  if (settings.toneAmplitudePercent == 0 || settings.toneAmplitudePercent > 100) {
    settings.toneAmplitudePercent = DEFAULT_TONE_AMPLITUDE_PERCENT;
  }

  if (settings.foxNumber < 1 || settings.foxNumber > 5) {
    settings.foxNumber = DEFAULT_FOX_NUMBER;
  }

  // Disable transmitter if no callsign is set.
  settings.isConfigured = (strlen(settings.callsign) > 0);

  // Disable transmitter if transmit frequency is out of band.
  uint32_t transmitFreqHz = settings.transmitFreqMHz * 1e6;
  uint16_t deviationMarginHz = FM_DEVIATION_HZ * 2;
  uint32_t minFreqHz = MIN_FREQ_MHZ * 1e6 + deviationMarginHz;
  uint32_t maxFreqHz;
  if (settings.ituZone == 1) {
    maxFreqHz = MAX_FREQ_MHZ_ITU1 * 1e6 - deviationMarginHz;
  } else {
    maxFreqHz = MAX_FREQ_MHZ * 1e6 - deviationMarginHz;
  }
  if (transmitFreqHz < minFreqHz || transmitFreqHz > maxFreqHz) {
    settings.isConfigured = false;
  }
}

bool settingsChanged() {
  bool changed = false;

  // If the marker file can be opened for reading check for a match, assume regen needed if file open fails.
  if (file.open(&root, SETTINGS_CRC, O_RDONLY)) {
    int savedCrc;
    file.read((void*)&savedCrc, sizeof(savedCrc));
    file.close();
    if (savedCrc == settingsCrc) {
      return false;
    }
  }

  file.close();
  return true;
}

// Generates an audio morse code ID from the provided callsign.
void generateMorseAudio() {
  openRoot();
  if (!file.open(&root, CALLSIGN_WAV, O_RDWR | O_CREAT)) {
    Serial.println("Failed to open .callsign.wav");
    return;
  }

  // Remove the existing data, if any.
  file.remove();
  if (!file.open(&root, CALLSIGN_WAV, O_RDWR | O_CREAT)) {
    Serial.println("Failed to re-open .callsign.wav after nuking the old one.");
    return;
  }

  // Write wav header.
  file.write(wavHeader, sizeof(wavHeader));

  const int sampleRate = AUDIO_SAMPLE_RATE_HZ;
  const int toneFreq = settings.morseToneHz;
  const double ditLengthSec = 1.2f / settings.morseWPM;
  const double interCharLengthSec = 1.2f / settings.farnsworthWPM * 3;
  const double riseFall = (1.0f / 3.0f) * ditLengthSec * sampleRate;

  const int amplitude = (settings.toneAmplitudePercent * 32767) / 100;
  const double toneStep = 2.0f * PI * toneFreq / sampleRate;

  auto writeTone = [&](double durationSec) {
    int samples = (int)(durationSec * sampleRate);
    for (int i = 0; i < samples; i++) {
      double envelope = 1.0f;
      if (i < riseFall) envelope = i / riseFall;
      else if (i > samples - riseFall) envelope = (samples - i) / riseFall;
      int16_t sample = (int16_t)(amplitude * envelope * sinf(toneStep * i));
      file.write((uint8_t*)&sample, 2);
    }
  };

  auto writeSilence = [&](double durationSec) {
    int samples = (int)(durationSec * sampleRate);
    int16_t zero = 0;
    for (int i = 0; i < samples; i++) {
      file.write((uint8_t*)&zero, 2);
    }
  };

  const char* morseTable[36] = {
    ".-", "-...", "-.-.", "-..", ".", "..-.", "--.", "....", "..",
    ".---", "-.-", ".-..", "--", "-.", "---", ".--.", "--.-", ".-.",
    "...", "-", "..-", "...-", ".--", "-..-", "-.--", "--..",
    "-----", ".----", "..---", "...--", "....-",
    ".....", "-....", "--...", "---..", "----."
  };

  auto getMorse = [&](char c) -> const char* {
    if (c >= 'A' && c <= 'Z') return morseTable[c - 'A'];
    if (c >= '0' && c <= '9') return morseTable[c - '0' + 26];
    return "";
  };

  // ARDF identifier (MOE/MOI/MOS/MOH/MO5) followed by callsign.
  // foxNumber 1-5 maps to identifiers per JARL ARDF rules.
  const char* ardfIdentifiers[] = { "MOE", "MOI", "MOS", "MOH", "MO5" };
  uint8_t idx = (settings.foxNumber >= 1 && settings.foxNumber <= 5)
                  ? settings.foxNumber - 1 : 0;
  const char* identifier = ardfIdentifiers[idx];

  auto writeString = [&](const char* str) {
    for (int i = 0; str[i]; i++) {
      const char* symbol = getMorse(str[i]);
      if (i != 0) writeSilence(interCharLengthSec);
      for (int j = 0; symbol[j]; j++) {
        if (j != 0) writeSilence(ditLengthSec);
        if (symbol[j] == '.') writeTone(ditLengthSec);
        else if (symbol[j] == '-') writeTone(3 * ditLengthSec);
      }
    }
  };

  writeSilence(interCharLengthSec);
  writeString(identifier);
  writeSilence(interCharLengthSec);
  writeString(settings.callsign);
  file.close();

  // Write a marker to indicate that the current callsign was generated.
  file.open(&root, SETTINGS_CRC, O_RDWR | O_CREAT);
  file.write((const void*)&settingsCrc, sizeof(settingsCrc));
  file.close();

  closeRoot();
}

// Regenerates morse code ID audio if the callsign has changed.
void generateMorseIfNeeded() {
  openRoot();
  bool regenerate = true;

  // Check for changes in settings file.
  if (!settingsChanged()) {
    regenerate = false;
  }

  // Force regen if the callsign audio file is missing.
  if (!root.exists(CALLSIGN_WAV)) {
    regenerate = true;
  }
  closeRoot();

  if (regenerate) {
    Serial.println("Detected settings change, generating new callsign audio");
    generateMorseAudio();
  }
}

// Remove junk, load settings and audio data. Generate morse ID audio if necessary.
void loadFlashData() {
  flashCleanup();
  loadSettings();
  generateMorseIfNeeded();
}

// Enables and disables the si5351 clock output and the RF amplifier.
void setSi5351Output(bool enabled) {
  if (enabled && settings.dutyCyclePercent > 0) {
    si5351.output_enable(SI5351_CLOCK_OUTPUT, 1);
    digitalWrite(AMP_EN, LOW);
    digitalWrite(LED_BUILTIN, HIGH);
  } else {
    si5351.output_enable(SI5351_CLOCK_OUTPUT, 0);
    digitalWrite(AMP_EN, HIGH);
    digitalWrite(LED_BUILTIN, LOW);
  }
}

// Sets the output frequency of the si5351 based on a given deviation from the center frequency.
void setFrequencyOffset(double deviation) {
  uint64_t freq = (uint64_t)(((settings.transmitFreqMHz * 1e6) + deviation) * 100);
  uint64_t pll_freq = freq * SI5351_CLOCK_DIV;
  si5351.set_pll(pll_freq, SI5351_PLL);
}

// Sleeps until it is time to write the next sample, based on the start of the cycle writing the current sample.
void delayForNextSample(uint32_t start) {
  uint32_t sampleDelta = 1000000UL / AUDIO_SAMPLE_RATE_HZ + SAMPLE_WRITE_CORR_US;

  // At the boundary of micros() overflow. Sleep until the appropriate time AFTER the overflow.
  // Otherwise just sleep for the appropriate delta.
  if ((MAX_UINT32 - start) < sampleDelta) {
    while (micros() > start || micros() < (sampleDelta - (MAX_UINT32 - start)))
      ;
  } else {
    while (micros() - start < sampleDelta)
      ;
  }
}

// Generates narrowband frequency modulated RF from a given audio file.
uint32_t playAudio(const char* filename) {
  if (hostMounted) return 0;  // Refuse to play audio if the host is trying to use the filesystem.
  openRoot();
  if (!file.open(&root, filename, O_RDWR | O_CREAT)) {
    Serial.println("Failed to open audio file.");
    return 0;
  }

  // Load WAV header and validate
  uint32_t dataStart = 44;
  char header[44];
  if (file.read(header, 44) != 44) return 0;
  if (strncmp(header, "RIFF", 4) != 0 || strncmp(header + 8, "WAVE", 4) != 0) return 0;

  #ifdef DEBUG
  uint32_t startMicros = micros();
  #endif

  uint32_t numSamples = 0;
  int16_t sample;
  while (file.read((uint8_t*)&sample, 2) == 2) {
    // End playback early if host is trying to use the filesystem.
    if (hostMounted) {
      return 0;
    }
    uint32_t start = micros();

    // Frequency deviation mapping
    double deviation = ((double)sample * FM_DEVIATION_HZ) / 32767;
    setFrequencyOffset(deviation);

    // Wait until next sample time
    numSamples++;
    delayForNextSample(start);
  }

  #ifdef DEBUG
  uint32_t endMicros = micros();
  Serial.print("Total time (us) ");
  Serial.print(endMicros - startMicros);
  Serial.print(" total samples ");
  Serial.print(numSamples);
  Serial.print(" us per sample ");
  Serial.println((double)(endMicros - startMicros) / numSamples);
  #endif

  file.close();
  closeRoot();
  uint32_t audioLengthMs = numSamples * 1000 / AUDIO_SAMPLE_RATE_HZ;
  return audioLengthMs;
}

// Polls SYNC_PIN and updates syncEpochMs when an active-LOW pulse is detected.
// Returns true if a sync event occurred.
static bool checkSync() {
  if (digitalRead(SYNC_PIN) == LOW) {
    syncEpochMs = millis();
    while (digitalRead(SYNC_PIN) == LOW) delay(1);  // Wait for release (debounce).
    Serial.println("SYNC received: cycle epoch reset.");
    return true;
  }
  return false;
}

// Plays audio and morse ID within the assigned 12-second ARDF slot.
// Foxes share a 60-second cycle; fox N transmits starting at (N-1)*12s from
// the last sync pulse (or power-on if no sync has been received).
// Connect a common SYNC_PIN wire to all foxes and pulse it LOW simultaneously
// to align all units. See HARDWARE.md for the start box circuit.
void audioTask() {
  const uint32_t CYCLE_MS = 60000;
  const uint32_t SLOT_MS  = 12000;

  while (true) {
    if (hostMounted) {  // Cancel task if the host is trying to use the filesystem.
      setSi5351Output(false);
      break;
    }

    if (!settings.isConfigured) {
      checkSync();
      delay(10);
      continue;
    }

    uint32_t slotOffsetMs = (uint32_t)(settings.foxNumber - 1) * SLOT_MS;

    // Poll until this fox's slot starts, checking SYNC_PIN every 1ms.
    while (true) {
      if (checkSync()) continue;  // Epoch reset; recalculate position.
      uint32_t posInCycle = (millis() - syncEpochMs) % CYCLE_MS;
      if (posInCycle >= slotOffsetMs && posInCycle < slotOffsetMs + SLOT_MS) break;
      delay(1);
    }

    // 1. Carrier ON (unmodulated) at slot start.
    uint32_t txStart = millis();
    setSi5351Output(true);

    // 2. Transmit morse ID. Skipped in test mode.
    if (!test_mode) {
      playAudio(CALLSIGN_WAV);
    }

    // 3. Hold unmodulated carrier for the remainder of the slot, then OFF.
    uint32_t elapsed = millis() - txStart;
    if (elapsed < SLOT_MS) {
      delay(SLOT_MS - elapsed);
    }
    setSi5351Output(false);
  }
}
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
void loop() {
}

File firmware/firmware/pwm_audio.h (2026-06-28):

#pragma once

#include <Arduino.h>
#include <hardware/pwm.h>

// PWM audio output driver for RP2040.
// Outputs 10-bit PWM at ~122 kHz carrier. An external RC low-pass filter
// converts the PWM signal to an analog voltage for the DRA818V MIC input.
//
// Recommended LPF (RC) values:
//   R = 1 kΩ, C = 33 nF  →  fc ≈ 4.8 kHz  (passes 5 kHz audio band)
//   R = 1 kΩ, C = 10 nF  →  fc ≈ 15.9 kHz (wider, more ripple on MIC)
// Use 1 kΩ / 33 nF as the primary design target.
//
// Schematic:
//   PWM_AUDIO_PIN ──[1kΩ]──┬── DRA818V MIC pin
//                          │
//                        [33nF]
//                          │
//                         GND
//
// DRA818V MIC input level: ~10 mV RMS typical for 3 kHz deviation.
// Adjust AUDIO_PWM_SCALE to calibrate deviation.

#define PWM_AUDIO_PIN     15u   // GPIO15 → LPF → DRA818V MIC
#define PWM_AUDIO_BITS    10    // 10-bit resolution (1024 levels)
#define PWM_AUDIO_WRAP    1023  // pwm_set_wrap value

// Attenuation factor applied to 16-bit PCM samples before PWM output.
// Range 1–100. Lower values reduce FM deviation on the DRA818V.
// Start at 30 and adjust empirically with a calibrated SDR.
#define AUDIO_PWM_SCALE   30

// Initialises the PWM slice for audio output.
// Call once during setup(), before any pwm_audio_write() calls.
void pwm_audio_init();

// Writes one 16-bit signed PCM sample to the PWM output.
// sample: signed 16-bit PCM value (-32768 to +32767).
// Converts to unsigned 10-bit PWM level centred at mid-scale (512).
void pwm_audio_write(int16_t sample);

// Sets PWM output to the silent (mid-scale) level.
// Call when carrier is ON but no audio is playing.
void pwm_audio_silence();

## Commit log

2026-04-16 PicoFox r3
    [Enclosure Bottom.stl, Enclosure Top.stl, kicad.kicad_pcb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]
2026-06-28 fix(firmware): set default freq and ITU zone for Japan
    [firmware.ino]
2026-06-28 feat(firmware): add FOX_NUMBER setting for ARDF slot control
2026-06-28 feat(firmware): implement 60s ARDF slot control in audioTask
2026-06-28 docs: add Japanese README and BOM with Japanese suppliers
2026-06-28 docs/feat: add DRA818V driver stubs, PWM audio, and hardware docs
2026-06-28 docs: consolidate BOM into single Japan ARDF configuration
2026-06-28 docs: add text-based schematic with ASCII diagrams
2026-06-28 docs: update CLAUDE.md to reflect current implementation
2026-06-28 docs: fix regulatory note to reflect JARD certification for homebuilt transceivers
